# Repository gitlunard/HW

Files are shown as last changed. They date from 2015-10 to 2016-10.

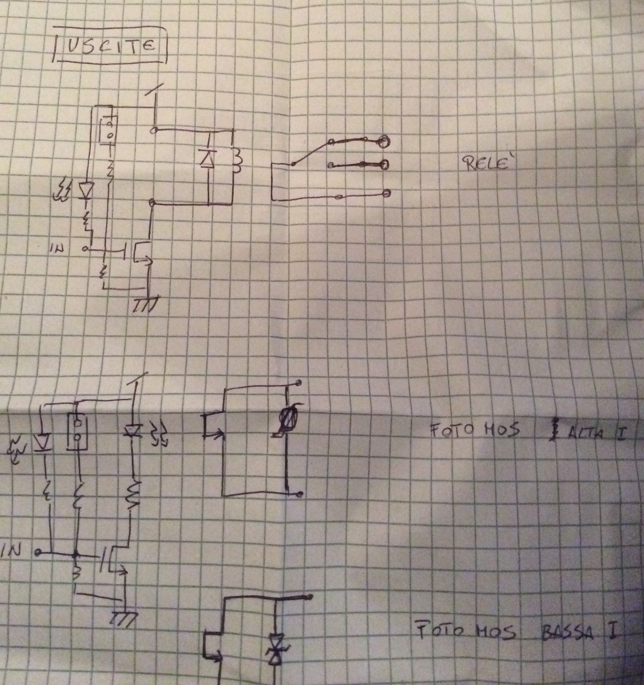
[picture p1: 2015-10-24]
hw-input/00-000-Documenti/Uscite.JPG

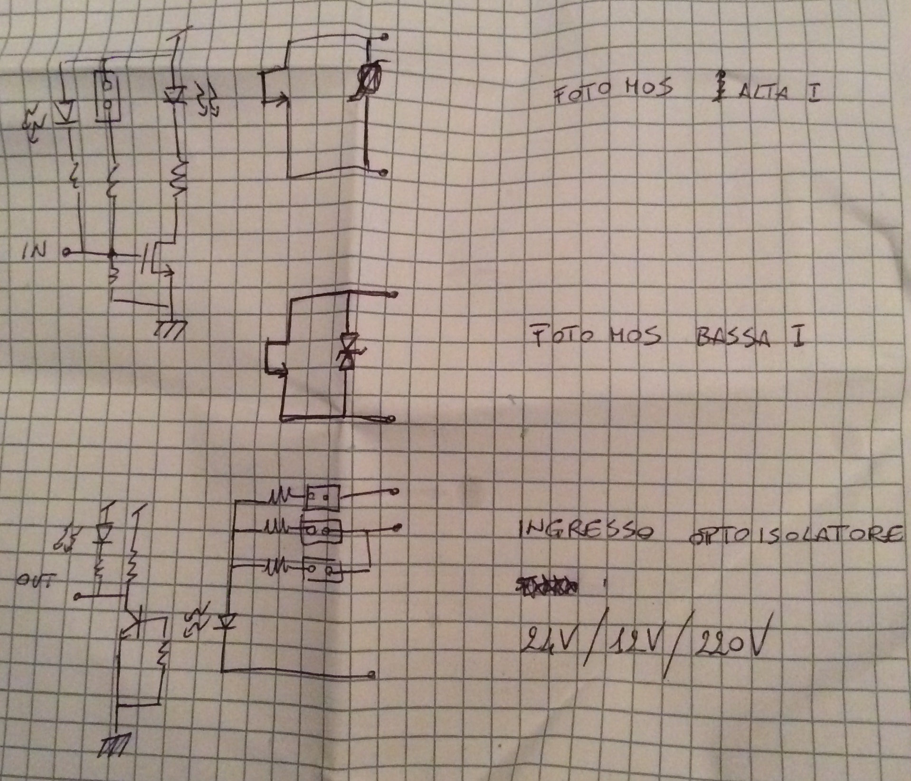
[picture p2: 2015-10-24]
hw-output/00-000-Documenti/ingresso.JPG

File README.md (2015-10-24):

Il progetto è descritto nella cartella hw-doc.
Essendo il progetto giovane, qualcosa potrebbe mancare!!! Aiutaci a completarlo!!!

Per scrivere la documentazione è preferibile utilizzare libreoffice. 
( Lo sappiamo, sull'argomento tool documentazione si apre una discussione infinita...ma abbi pazienza usa libreoffice!)

*********************************************************************************************************************
Se le tue idee, la tua esperienza ed il tuo tempo si comprano con dei soldi allora questo non è il progetto 
che fa per te. Ti consigliamo di lasciar perdere!!!!

Chi ha avviato questo semplice progetto è dell'idea che: 

- Se fai quello che ti piace i soldi non ti servono!!!
- Le idee geniali nascono qunando non ci sono nè pressioni economiche nè pressioni sulle scadenze!!

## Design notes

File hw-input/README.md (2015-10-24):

Progetto HardWare scheda input output

- Input: scheda per due ingressi digitali con optoisolatore. Tensioni di ingresso regolabili.
- Output: circuito stampato unico per diverse tipologie di uscita, photoMOS di potenza, photoMOS di segnale oppure relè. Due uscite per scheda.
- Input/Output: scheda per un ingresso e un'uscita della tipologia definita in Input e Output.

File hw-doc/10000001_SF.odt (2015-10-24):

Specifica fisica unità 10000001

Compilato: L. Colla – L. Balestrieri

Edizione: 1

Revisione: 52

Stato: Bozza

Modifiche: tolti capitoli separati in altri documenti

Data creazione: 13/10/2015

# Indice

# Descrizione generale

Unità di ingressi, uscite digitali isolate.

L'obbietivo è realizzare moduli piccoli e funzionali che realizzano diverse combinazioni di ingressi e uscite, con diverse specifiche di tensione e corrente.

Si vuole modularità di comando, deve essere possibile un comando tramite bus I2C oppure accesso diretto agli input output a 3.3-5Vdc.

## Unità ingressi

PN: 10000001

Unità che prevede due ingressi optoisolati.

La corrente assorbita deve essere al massimo 10 [mA].

La tensione in ingresso deve poter essere programmabile secondo la tabella seguente.

Tensione nominale [V] | Soglia spegnimento [V] | Soglia accensione [V]
5 d.c. | 1,5 | 2,5
12 d.c. | 3 | 8
24 d.c. | 3 | 18
48 d.c. | 5 | 40
220 a.c. | 10 | 160

Le tensioni da tenere in maggior considerazione sono 5, 24 e 220.

## Unità uscite potenza

PN: 10000004

Unità che prevede due uscite a relè o photoMOS.

La corrente in uscita massima deve essere almeno 16A.

La tensione sull'uscita dipenderà dal dispositivo montato indicativamente come la seguente tabella.

Tensione nominale [V] | Corrente [I]
5 d.c. | 5
12 d.c. | 5
24 d.c. | 5
48 d.c. | 10
220 a.c. | 16

Le tensioni da tenere in maggior considerazione sono 5, 24 e 220.

## Unità uscite di segnale

PN: 10000005

Unità che prevede due uscite a relè o photoMOS.

La corrente in uscita massima deve essere almeno 100mA.

La tensione sull'uscita dipenderà dal dispositivo montato indicativamente come la seguente tabella.

Tensione nominale [V] | Corrente [I]
5 d.c. | 500mA
12 d.c. | 250mA
24 d.c. | 250mA
48 d.c. | 250mA
220 a.c. | 100mA

Le tensioni da tenere in maggior considerazione sono 5, 24 e 220.

## Unità mista ingresso e uscita

Unità che prevede un ingresso di quelli già citati ed un'uscita di quelle già citate.

Saranno necessarie due unità distinte per uscita di potenza e uscita di segnale.

# Porte

## Lato logica

Porta a 4 pin per bus I2C e porta a 4 pin per input output diretto.

Il connettore dovrà essere a passo 2.54mm. Con occupazione prevista sia per mezzanina classica che per morsettiera con serraggio a molla.

Si dovrà rispettare il seguente pinout

### Pinout I2C

Pin | Nome | Descrizione
1 | +VDC | Polo positivo alimentazione DC
2 | I2C_SCL | Clock BUS I2C
3 | I2C_SDA | Clock BUS I2C
4 | GND | Massa alimentazione

### Pinout diretto

Pin | Nome | Descrizione
1 | +VDC | Polo positivo alimentazione DC
2 | CMD_IO_0 | Ingresso o uscita 0
3 | CMD_IO_1 | Ingresso o uscita 1
4 | GND | Massa alimentazione

La logica per il collegamento diretto deve essere programmata per funzionare a 3,3V ed essere tollerante fino ai 5,5V.

Nel caso delle uscite non dovranno assorbire dal pin di comando più di 10mA. Per questo motivo le uscite di potenza potrebbero aver bisogno di un transistor di pilotaggio.

### Selezione tipologia di comando

Sulla PCS devono essere possibili entrambi i tipi di comando.

La selezione deve essere fatta mediante variante di montaggio con jumper a saldare o resistenze da 0Ω.

## Lato campo

Porta a 4 pin che fornise due contatti puliti.

Il connettore dovrà essere a passo 5,08mm o 7,62mm. Con occupazione prevsta per morsettiera con serraggio a molla.

Si dovrà rispettare il seguente pinout

### Pinout

Pin | Nome | Descrizione
1 | IO_0_P | Polo positivo uscita numero 0
2 | IO_0_N | Polo negativo uscita numero 0
3 | IO_1_P | Polo positivo uscita numero 1
4 | IO_1_N | Polo negativo uscita numero 1

## Connettori di rimando

Devono essere previsti due connettori di rimando segnali. In questo modo è possibile connettere più moduli che condividono lo stesso BUS I2C ed anche lo stesso integrato I2C expander.

### Porta I2C

Il pinout rimane lo stesso della porta di ingresso, ma deve essere posto lateralmente e realizzato con connettore femmina a passo 2.54.

Il connettore deve prevedere i reofori lato bottom abbastanza lunghi da penetrare nel suo corrispettivo della scheda inferiore.

### Porta ingresso/uscita expander I2C

Il pinout dipende dall'expander utilizzato. Prendendo ad esempio il TCA9554 di TI si hanno 8 ingressi/uscite. Considerando che due porte vengono usate sull'unità base, devono essere rimandate 6 porte.

A fianco di questo connettore deve essere previsto un selettore (microswitch o ponticello a saldare) per determinare quale dei segnali vengono utilizzati dalle schede connesse alla principale.

L'expander I2C di esempio prevede 3 bit di indirizzo programmabile, quindi sullo stesso BUS si riescono ad ottenere 2³·8=64 tra ingressi e uscite.

Pin | Nome | Descrizione
1 | IO_2_CMD | Comando ingresso uscita 2
2 | IO_3_CMD | Comando ingresso uscita 3
3 | IO_4_CMD | Comando ingresso uscita 4
4 | IO_5_CMD | Comando ingresso uscita 5
5 | IO_6_CMD | Comando ingresso uscita 6
6 | IO_7_CMD | Comando ingresso uscita 7

## Indirizzi I2C

Nel caso di pilotaggio I2C va prevista la programmabilità dell'indirizzo attraverso ponticelli a saldare sulla PCS oppure attraverso microswitch.

## Meccanica

La porta lato logica e la porta lato campo dovranno essere su lati opposti della PCS così da facilitare lo sbroglio e ridurre le dimensioni.

Sui lati liberi devono essere piazzate le porte di rimando segnali, in modo che le schede possano essere affiancate o sovrapposte.

Dovranno essere previsti da 2 a 4 fori di fissaggio per viti M3 da decidere in base agli ingombri se metallizzarli o meno.

Se possibile si deve trovare un'involucro plastico idoneo prima dello sbroglio e regolare di conseguenza i fori di fissaggio.

Nello schema a blocchi seguente si descrive a grandi linee anche la disposizione meccanica dei componenti.

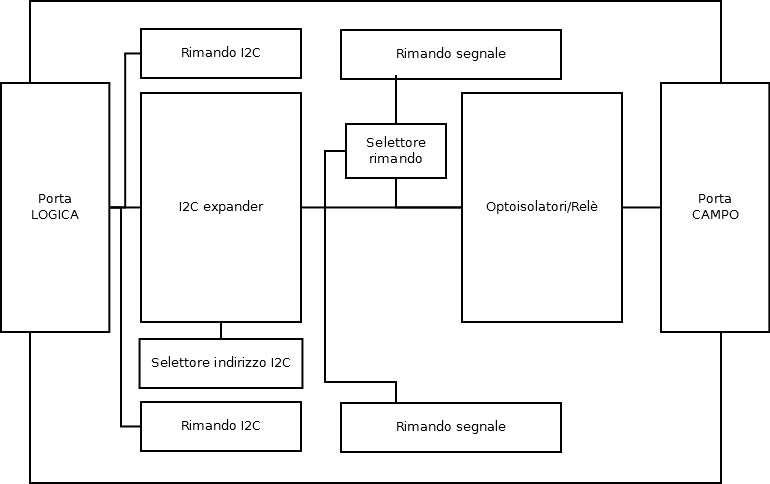
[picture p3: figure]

Illustrazione 1: Schema a blocchi unità IO

OpenS Elettronica condivisa - Specifica fisica unità 10000001

10000001_SF.odt Data: 13/10/2015 Pag. 8 - 8

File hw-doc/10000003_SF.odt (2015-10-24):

Specifica fisica unità 10000003

Compilato: L. Colla – L. Balestrieri

Edizione: 0

Revisione: 54

Stato: Bozza

Modifiche: nessuna

Data creazione: 22/11/2014

# Indice

# Descrizione generale

Unità di distribuzione alimentazione.

L'obbiettivo è di realizzare una scheda semplice di distribuzione alimentazione.

Data una alimentazione principale in ingresso, possibile anche 220Vac, deve essere distribuita a porte secondarie. Questo viene utilizzato per semplificare il cablaggio di diversi moduli di una unità principale.

In questa unità devono essere previsti gli alloggiamenti per eventuali dispositivi di protezione, come soppressori bidirezionali, induttori, filtri di modo comune, e varistori.

Va previsto un'assorbimento pari a 10A come carico delle piste.

# Porte

## Ingresso

Porta 3 pin.

Il connettore dovrà essere a passo 5,08mm o 7,62mm. Con occupazione prevsta per morsettiera con serraggio a molla.

Si dovrà rispettare il seguente pinout

### Pinout

Pin | Nome | Descrizione
1 | +V | Polo positivo rete di alimentazione
2 | -V | Polo negativo rete di alimentazione
3 | PGND | Terra di protezione

## Uscita

Porta 3 pin ripetuta due volte.

Il connettore dovrà essere a passo 5,08mm o 7,62mm. Con occupazione prevsta per morsettiera con serraggio a molla.

Si dovrà rispettare il seguente pinout per ogni porta

### Pinout

Pin | Nome | Descrizione
1 | +V | Polo positivo rete di alimentazione
2 | -V | Polo negativo rete di alimentazione
3 | PGND | Terra di protezione

## Connettori di rimando

Devono essere previsti due connettori di rimando segnali. In questo modo è possibile connettere più moduli che distribuiscono la stessa rete di alimentazione

Il pinout è il seguente

### Pinout

Pin | Nome | Descrizione
1 | +V | Polo positivo rete di alimentazione
2 | -V | Polo negativo rete di alimentazione
3 | PGND | Terra di protezione

## Meccanica

La porta ingresso e la porta uscita dovranno essere su lati opposti della PCS così da facilitare lo sbroglio e ridurre le dimensioni.

Sui lati liberi devono essere piazzate le porte di rimando segnali, in modo che le schede possano essere affiancate o sovrapposte.

Dovranno essere previsti da 2 a 4 fori di fissaggio per viti M3 da decidere in base agli ingombri se metallizzarli o meno.

Se possibile si deve trovare un'involucro plastico idoneo prima dello sbroglio e regolare di conseguenza i fori di fissaggio.

Nello schema a blocchi seguente si descrive a grandi linee anche la disposizione meccanica dei componenti.

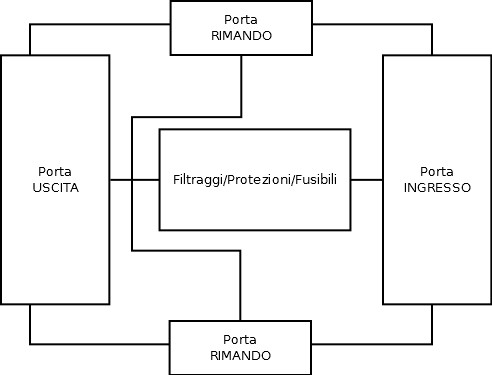
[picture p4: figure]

Illustrazione 1: Schema a blocchi distribuzione

OpenS Elettronica condivisa - Specifica fisica unità 10000003

10000003_SF.odt Data: 22/11/2014 Pag. 3 - 5

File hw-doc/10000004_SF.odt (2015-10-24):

Specifica fisica unità 10000004

Compilato: L. Colla – L. Balestrieri

Edizione: 0

Revisione: 62

Stato: Bozza

Modifiche: -

Data creazione: 09/03/2015

# Indice

# Descrizione generale

Unità di interfaccia seriale, deve realizzare la conversione dell'uscita seriale del microcontrollore a standard RS232 o USB 2.0.

Non vengono usati i pin relativi ai controlli di flusso, si portano solo i fili TX e RX.

## Standard RS232 su RJ45

Per la conversione a standard RS232 si usa il dispositivo RS3232 alimentabile tra 3V e 5V. Il connettore deve essere RJ45 senza led in pacchetto metallico.

## Standard USB su micro-B-USB

Usare il dispositivo FT232R per il passaggio diretto a USB 2.0. In sviluppi futuri è possibile usare anche l'alimentazione da USB per alimentare il convertitore e altre logiche esterne. Il connettore deve essere micro-B-USB standard per dispositivi portatili.

# Porte

## Lato microcontrollore

Porta a 4 pin per connesione bus seriale e alimentazione.

Il connettore dovrà essere a passo 2.54mm. Con occupazione prevista sia per mezzanina classica che per morsettiera con serraggio a molla.

Si dovrà rispettare il seguente pinout

### Pinout I2C

Pin | Nome | Descrizione
1 | +VDC | Polo positivo alimentazione DC
2 | SER_TX | Dato TX (uscita)
3 | SER_RX | Dato RX (ingresso)
4 | GND | Massa alimentazione

## Lato campo

### Pinout RJ45

Porta RJ45 con calotta metallica in standard console Cisco.

Si dovrà rispettare il seguente pinout

Riferimento: http://www.cisco.com/en/US/docs/security/pix/pix70/hw/installation/guide/append.html#wp1011710

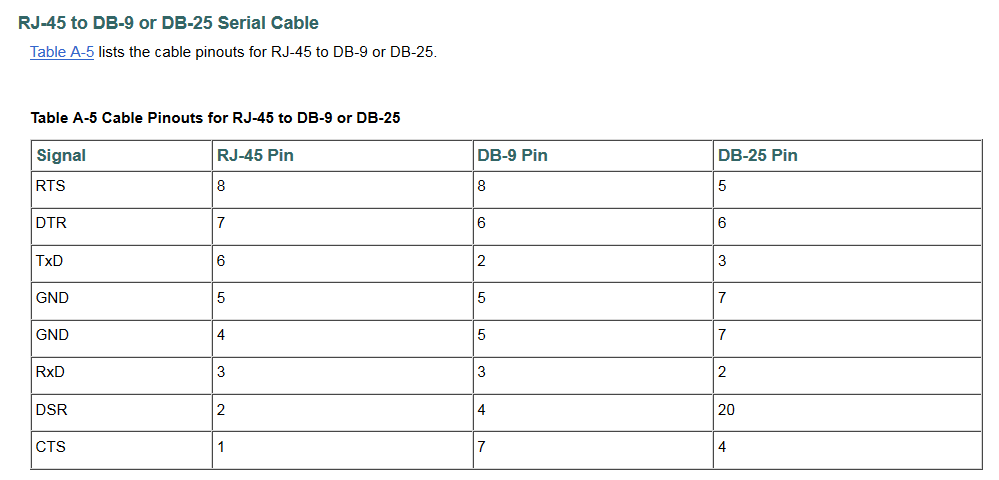
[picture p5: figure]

### Pinout USB

Porta micro-B con calotta metallica standard.

Pinout da verificare.

## Meccanica

La porta lato microcontrollore e la porta lato campo dovranno essere su lati opposti della PCS così da facilitare lo sbroglio e ridurre le dimensioni.

Dovranno essere previsti da 2 a 4 fori di fissaggio per viti M3 da decidere in base agli ingombri se metallizzarli o meno.

Se possibile si deve trovare un'involucro plastico idoneo prima dello sbroglio e regolare di conseguenza i fori di fissaggio.

Nello schema a blocchi seguente si descrive a grandi linee anche la disposizione meccanica dei componenti.

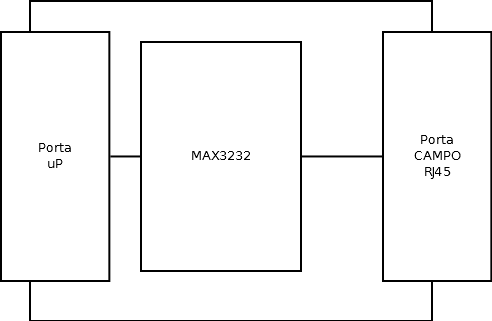
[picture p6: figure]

Illustrazione 1: Schema a blocchi seriale RJ45

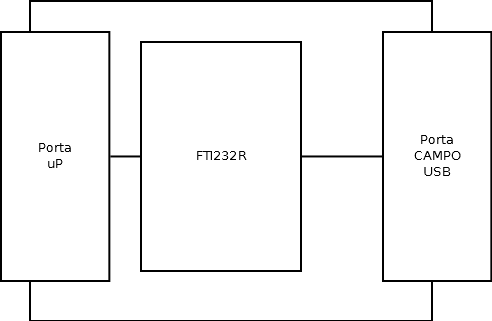
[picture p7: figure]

Illustrazione 2: Schema a blocchi seriale USB

OpenS Elettronica condivisa - Specifica fisica unità 1000000

10000004_SF.odt Data: 09/03/2015 Pag. 5 - 5

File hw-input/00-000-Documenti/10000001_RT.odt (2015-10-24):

Rapporto di test unità 10000001

Compilato: L. Colla – L. Balestrieri

Edizione: 0

Revisione: 58

Stato: Bozza

Modifiche:

Data creazione: 07/09/2015

# Indice

# Descrizione generale

Rapporto prove su prototipi scheda ingressi.

## PCB errato

I piani dei layer interni non sono stati aggiornati prima della produzione.

Il risultato sono il layer VCC e GND in corto, inoltre altre piste risultano annegate nei layer.

La scheda così come è risulta compromessa.

E' possibile utilizzare la scheda come sottomodulo, senza montare l'expander I2C.

Operazioni da eseguire.

- Eliminare tutti i componenti comrpesere tutte le resistenze 0Ω. Lasciare solamente la parte relativa all'optoisolatore e le sue resistenze di polarizzazione.
- Forare le vias di VDD e GND connesse a R10 e R11. E ricreare le connessioni filate verso il primo connettore libero.
- Collegare R1 per connettere IO_0_CMD a IO_2_CMD.
- Il comando IO_0_CMD è recuperato.
- Eliminare la vias a fianco del pin 4 di IC2 e ricreare la connessione andando al primo pin connesso a IO_3_CMD.
- Eliminare le vias di VDD e GND a fianco di R12 ed R13 e ricreare le connessioni filate verso il primo connettore libero.
- Il comando IO_1_CMD è recuperato.

OpenS Elettronica condivisa - Rapporto di test unità 10000001

10000001_RT.odt Data: 07/09/2015 Pag. 2 - 3

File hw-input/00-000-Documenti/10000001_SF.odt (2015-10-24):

Specifica fisica unità 10000001

Compilato: L. Colla – L. Balestrieri

Edizione: 1

Revisione: 6

Stato: Prima emissione

Modifiche: Pulizia documento con sole specifiche unità ingressi.

Aggiornamento documento per nuova versione HW

Data creazione: 17/10/2015

# Indice

# Descrizione generale

Unità di ingressi isolati.

L'obbietivo è realizzare moduli piccoli e funzionali che realizzano diverse funzioni di interfaccia verso il campo, tutti compatibili meccanicamente tra loro.

Si vuole modularità di comando, deve essere possibile un comando tramite bus I2C oppure accesso diretto agli input output a 3.3-5Vdc.

## Unità ingressi

Unità che prevede due ingressi optoisolati.

La corrente assorbita deve essere al massimo 10 [mA].

La tensione in ingresso deve poter essere programmabile secondo la tabella seguente.

Tensione nominale [V] | Soglia spegnimento [V] | Soglia accensione [V]
5 d.c. | 1,5 | 2,5
12 d.c. | 3 | 8
24 d.c. | 3 | 18
48 d.c. | 5 | 40
220 a.c. | 10 | 160

Le tensioni da tenere in maggior considerazione sono 5, 24 e 220.

# Porte

## Lato logica

Porta a 4 pin per bus I2C e porta a 4 pin per input output diretto.

Il connettore dovrà essere a passo 2.54mm. Con occupazione prevista sia per mezzanina classica che per morsettiera con serraggio a molla.

Si dovrà rispettare il seguente pinout

### Pinout I2C

Pin | Nome | Descrizione
1 | +VDC | Polo positivo alimentazione DC
2 | I2C_SCL | Clock BUS I2C
3 | I2C_SDA | Clock BUS I2C
4 | GND | Massa alimentazione

### Pinout diretto

Pin | Nome | Descrizione
1 | +VDC | Polo positivo alimentazione DC
2 | CMD_IO_0 | Ingresso o uscita 0
3 | CMD_IO_1 | Ingresso o uscita 1
4 | GND | Massa alimentazione

La logica per il collegamento diretto deve essere programmata per funzionare a 3,3V ed essere tollerante fino ai 5,5V.

### Selezione tipologia di comando

Sulla PCS devono essere possibili entrambi i tipi di comando.

La selezione deve essere fatta mediante variante di montaggio con jumper a saldare o resistenze da 0Ω.

## Lato campo

Porta a 4 pin che fornise due contatti puliti.

Il connettore dovrà essere a passo 5,08mm o 7,62mm. Con occupazione prevsta per morsettiera con serraggio a molla.

Si dovrà rispettare il seguente pinout

### Pinout

Pin | Nome | Descrizione
1 | IO_0_P | Polo positivo uscita numero 0
2 | IO_0_N | Polo negativo uscita numero 0
3 | IO_1_P | Polo positivo uscita numero 1
4 | IO_1_N | Polo negativo uscita numero 1

## Connettori di rimando

Devono essere previsti due connettori di rimando segnali. In questo modo è possibile connettere più moduli che condividono lo stesso BUS I2C ed anche lo stesso integrato I2C expander.

### Porta I2C

Il pinout rimane lo stesso della porta di ingresso, ma deve essere posto lateralmente e realizzato con connettore femmina a passo 2.54.

Il connettore deve prevedere i reofori lato bottom abbastanza lunghi da penetrare nel suo corrispettivo della scheda inferiore.

### Porta ingresso/uscita expander I2C

Il pinout dipende dall'expander utilizzato. Prendendo ad esempio il TCA9554 di TI si hanno 8 ingressi/uscite. Considerando che due porte vengono usate sull'unità base, devono essere rimandate 6 porte.

A fianco di questo connettore deve essere previsto un selettore (microswitch o ponticello a saldare) per determinare quale dei segnali vengono utilizzati dalle schede connesse alla principale.

L'expander I2C di esempio prevede 3 bit di indirizzo programmabile, quindi sullo stesso BUS si riescono ad ottenere 2³·8=64 tra ingressi e uscite.

Pin | Nome | Descrizione
1 | IO_2_CMD | Comando ingresso uscita 2
2 | IO_3_CMD | Comando ingresso uscita 3
3 | IO_4_CMD | Comando ingresso uscita 4
4 | IO_5_CMD | Comando ingresso uscita 5
5 | IO_6_CMD | Comando ingresso uscita 6
6 | IO_7_CMD | Comando ingresso uscita 7

## Indirizzi I2C

Nel caso di pilotaggio I2C va prevista la programmabilità dell'indirizzo attraverso ponticelli a saldare sulla PCS oppure attraverso microswitch.

## Meccanica

La porta lato logica e la porta lato campo dovranno essere su lati opposti della PCS così da facilitare lo sbroglio e ridurre le dimensioni.

Sui lati liberi devono essere piazzate le porte di rimando segnali, in modo che le schede possano essere affiancate o sovrapposte.

Dovranno essere previsti da 2 a 4 fori di fissaggio per viti M3 da decidere in base agli ingombri se metallizzarli o meno.

Se possibile si deve trovare un'involucro plastico idoneo prima dello sbroglio e regolare di conseguenza i fori di fissaggio.

Nello schema a blocchi seguente si descrive a grandi linee anche la disposizione meccanica dei componenti.


Illustrazione 1: Schema a blocchi unità IO

## Possibili tipologie di comando

### Schmitt trigger

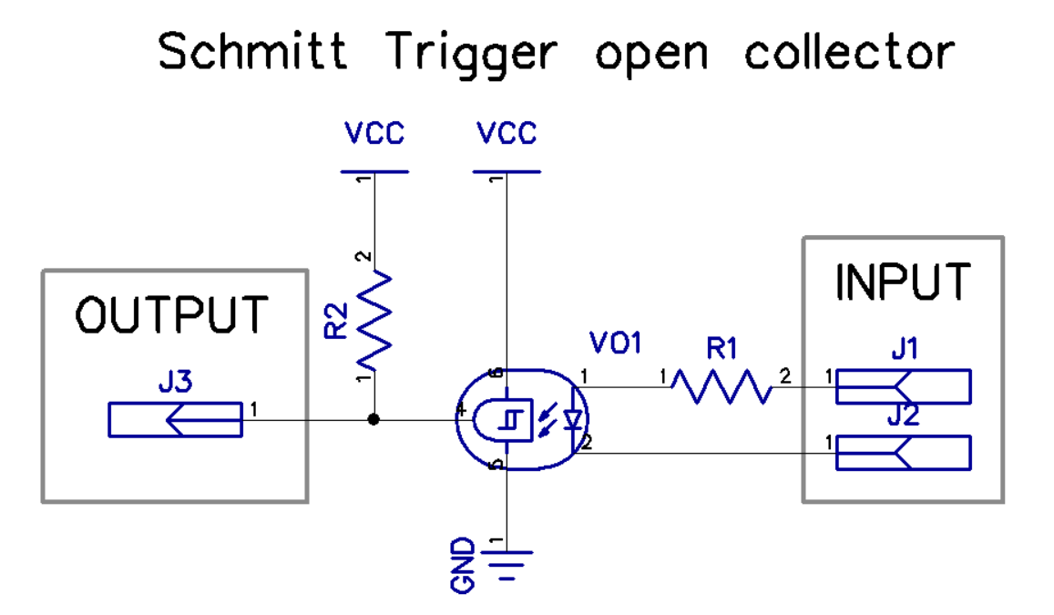
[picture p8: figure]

Tipologia optoisolatore Fairchild H11L1M 0,88€

Si può fare solo la configurazione pull-down perchè l'optoisolatore esce come un open-collector. Integra già il trigger di Schmitt riducendo notevolmente i disturbi.

### General-purpose pull-down

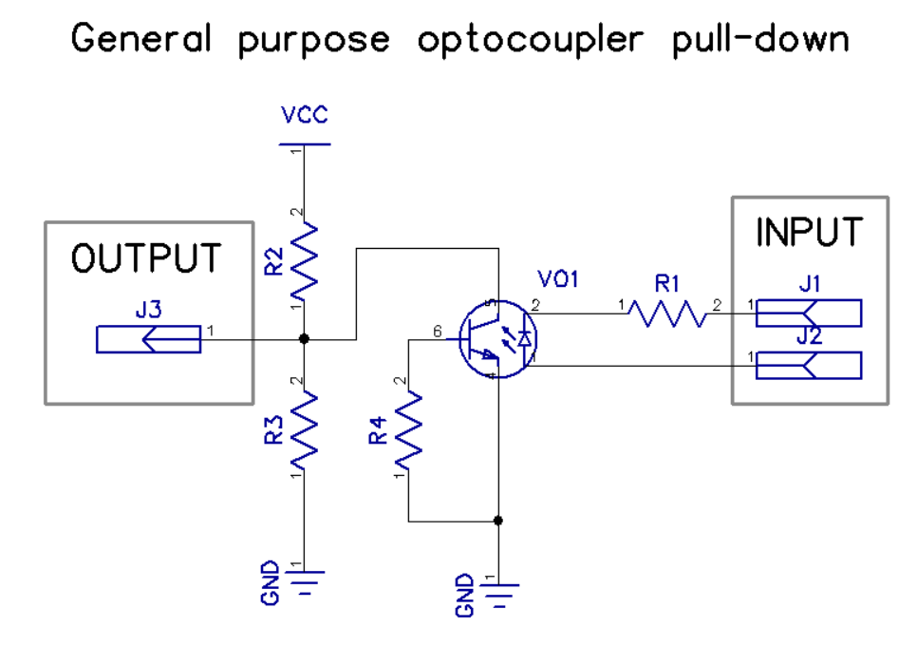
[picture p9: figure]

Tipologia optoisolatore 4N35M, H11A1, TLP291 0,5€

Si può decidere di spostare a pull-up l'optoaccoppiatore. Si può optare per optoisolatori semplici e piccoli come TLP291 senza la connessione di base. Per quanto riguarda il 4N35 è un package standard, quindi con molte alternative.

### Versione mista

Si può realizzare la seconda versione ed in uscita inserire uno Schmitt trigger a componenti discreti o integrato, ma considerando il costo della prima soluzione risulta sicuramente più vantaggiosa.

### Considerazioni tensione in ingresso e resistenza di polarizzazione opto

Nella versione più semplice è costretti ad usare una resistenza per polarizzare il diodo dell'optoaccoppiatore. Questo definisce direttamente la tensione di ingresso e la soglia di attivazione. E' possibile sostituire la resistenza con il circuito seguente, questo permette di adattarsi alla tensione di ingresso, rimane problematica la definizione della soglia di attivazione, in questo caso sarebbe sempre fissa allo stesso valore.

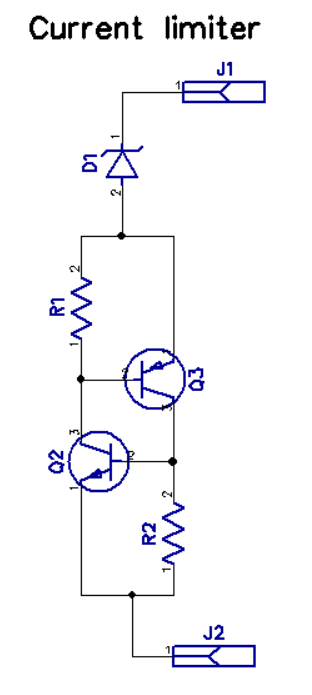
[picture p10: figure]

OpenS Elettronica condivisa - Specifica fisica unità 10000001

10000001_SF.odt Data: 17/10/2015 Pag. 8 - 8

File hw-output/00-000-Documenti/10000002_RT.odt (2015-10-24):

Rapporto di test unità 10000002

Compilato: L. Colla – L. Balestrieri

Edizione: 0

Revisione: 54

Stato: Bozza

Modifiche:

Data creazione: 07/09/2015

# Indice

# Descrizione generale

Rapporto prove su prototipi scheda uscite.

## PCB errato

I piani dei layer interni non sono stati aggiornati prima della produzione.

Il risultato sono il layer VCC e GND in corto.

Sono stati forati 3 vias attorno a C1 e C2 per eliminare il corto e riportate le connessioni sui pin 1 e 4 del primo connettore libero.

OpenS Elettronica condivisa - Rapporto di test unità 10000002

10000002_RT.odt Data: 07/09/2015 Pag. 1 - 3

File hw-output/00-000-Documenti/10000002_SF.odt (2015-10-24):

Specifica fisica unità 10000002

Compilato: L. Colla – L. Balestrieri

Edizione: 0

Revisione: 20

Stato: Prima emissione

Modifiche: Pulizia documento con sole specifiche unità uscite.

Aggiornamento documento per nuova versione HW

Data creazione: 17/10/2015

# Indice

# Descrizione generale

Unità uscite digitali isolate.

L'obbietivo è realizzare moduli piccoli e funzionali che realizzano diverse funzioni di interfaccia verso il campo, tutti compatibili meccanicamente tra loro.

Si vuole modularità di comando, deve essere possibile un comando tramite bus I2C oppure accesso diretto agli input output a 3.3-5Vdc.

## Unità uscite potenza

Unità che prevede due uscite a relè o photoMOS.

La tensione sull'uscita e la relativa corrente massima dipenderà dal dispositivo montato indicativamente come la seguente tabella.

Tensione nominale [V] | Corrente [I]
5 d.c. | 5
12 d.c. | 5
24 d.c. | 5
48 d.c. | 10
220 a.c. | 16

Le tensioni da tenere in maggior considerazione sono 5, 24 e 220.

# Porte

## Lato logica

Porta a 4 pin per bus I2C e porta a 4 pin per input output diretto.

Il connettore dovrà essere a passo 2.54mm. Con occupazione prevista sia per mezzanina classica che per morsettiera con serraggio a molla.

Si dovrà rispettare il seguente pinout

### Pinout I2C

Pin | Nome | Descrizione
1 | +VDC | Polo positivo alimentazione DC
2 | I2C_SCL | Clock BUS I2C
3 | I2C_SDA | Clock BUS I2C
4 | GND | Massa alimentazione

### Pinout diretto

Pin | Nome | Descrizione
1 | +VDC | Polo positivo alimentazione DC
2 | CMD_IO_0 | Ingresso o uscita 0
3 | CMD_IO_1 | Ingresso o uscita 1
4 | GND | Massa alimentazione

La logica per il collegamento diretto deve essere programmata per funzionare a 3,3V ed essere tollerante fino ai 5,5V.

Ogni uscita non dovrà assorbire dal pin di comando più di 10mA. Per questo motivo le uscite di potenza potrebbero aver bisogno di un transistor di pilotaggio.

### Selezione tipologia di comando

Sulla PCS devono essere possibili entrambi i tipi di comando.

La selezione deve essere fatta mediante variante di montaggio con jumper a saldare o resistenze da 0Ω.

## Lato campo

Porta a 4 pin che fornise due contatti puliti.

Il connettore dovrà essere a passo 5,08mm o 7,62mm. Con occupazione prevsta per morsettiera con serraggio a molla.

Si dovrà rispettare il seguente pinout

### Pinout

Pin | Nome | Descrizione
1 | IO_0_P | Polo positivo uscita numero 0
2 | IO_0_N | Polo negativo uscita numero 0
3 | IO_1_P | Polo positivo uscita numero 1
4 | IO_1_N | Polo negativo uscita numero 1

## Connettori di rimando

Devono essere previsti due connettori di rimando segnali. In questo modo è possibile connettere più moduli che condividono lo stesso BUS I2C ed anche lo stesso integrato I2C expander.

### Porta I2C

Il pinout rimane lo stesso della porta di ingresso, ma deve essere posto lateralmente e realizzato con connettore femmina a passo 2.54.

Il connettore deve prevedere i reofori lato bottom abbastanza lunghi da penetrare nel suo corrispettivo della scheda inferiore.

### Porta ingresso/uscita expander I2C

Il pinout dipende dall'expander utilizzato. Prendendo ad esempio il TCA9554 di TI si hanno 8 ingressi/uscite. Considerando che due porte vengono usate sull'unità base, devono essere rimandate 6 porte.

A fianco di questo connettore deve essere previsto un selettore (microswitch o ponticello a saldare) per determinare quale dei segnali vengono utilizzati dalle schede connesse alla principale.

L'expander I2C di esempio prevede 3 bit di indirizzo programmabile, quindi sullo stesso BUS si riescono ad ottenere 2³·8=64 tra ingressi e uscite.

Pin | Nome | Descrizione
1 | IO_2_CMD | Comando ingresso uscita 2
2 | IO_3_CMD | Comando ingresso uscita 3
3 | IO_4_CMD | Comando ingresso uscita 4
4 | IO_5_CMD | Comando ingresso uscita 5
5 | IO_6_CMD | Comando ingresso uscita 6
6 | IO_7_CMD | Comando ingresso uscita 7

## Indirizzi I2C

Nel caso di pilotaggio I2C va prevista la programmabilità dell'indirizzo attraverso ponticelli a saldare sulla PCS oppure attraverso microswitch.

## Meccanica

La porta lato logica e la porta lato campo dovranno essere su lati opposti della PCS così da facilitare lo sbroglio e ridurre le dimensioni.

Sui lati liberi devono essere piazzate le porte di rimando segnali, in modo che le schede possano essere affiancate o sovrapposte.

Dovranno essere previsti da 2 a 4 fori di fissaggio per viti M3 da decidere in base agli ingombri se metallizzarli o meno.

Se possibile si deve trovare un'involucro plastico idoneo prima dello sbroglio e regolare di conseguenza i fori di fissaggio.

Nello schema a blocchi seguente si descrive a grandi linee anche la disposizione meccanica dei componenti.


Illustrazione 1: Schema a blocchi unità IO

## Possibili tipologie di comando

A seconda del tipo di integrato I2C utilizzato possono presentarsi diverse tipologie di driver in uscita, push-pull o open-drain, a bassa o ad alta corrente.

### Driver push-pull

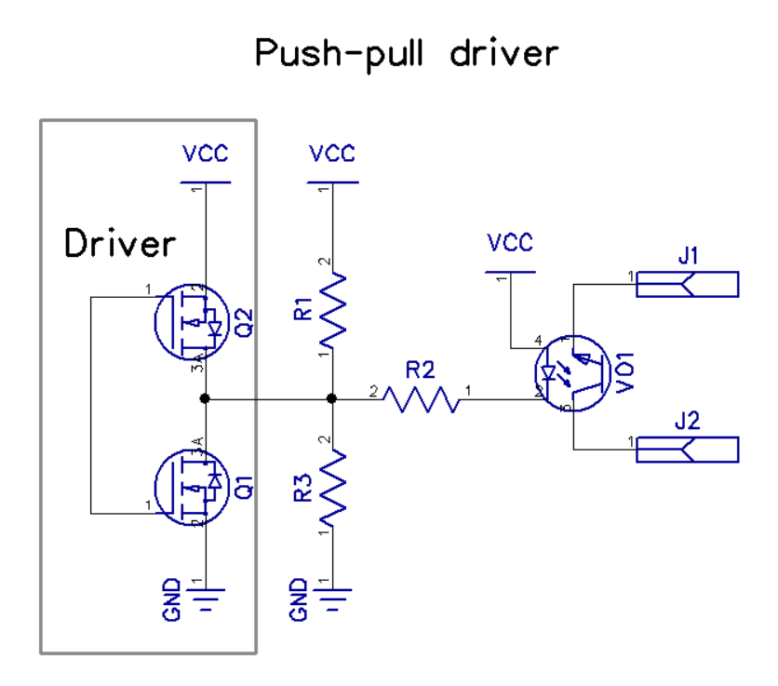
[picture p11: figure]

Se il driver ha la possibilità di pilotare direttamente il diodo del photoMOS, si può usare questo schema, con R2 si definisce la corrente di pilotaggio del diodo. R1 ed R3 definiscono la situazione di partenza del comando.

### Driver push-pull con transistor driver

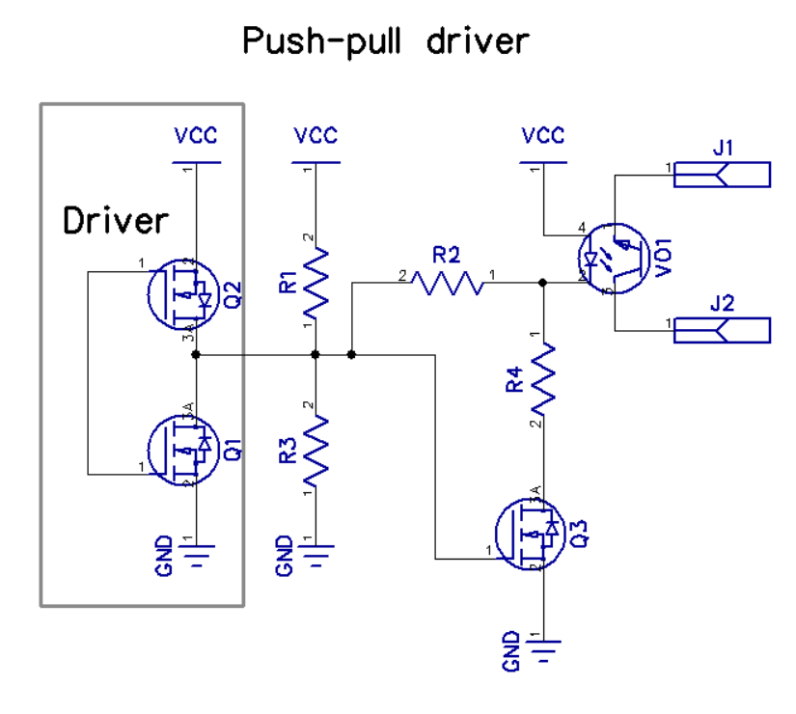
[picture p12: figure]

Il driver push-pull può essere a bassa corrente e pilotare il transistor che pilota il diodo. In questo caso montando R2 e smontando Q3 e R4 si torna al caso di pilotaggio diretto. R4 definisce la corrente di pilotaggio del diodo. R1 ed R3 definiscono la situazione di partenza del comando. In questo caso il driver può essere anche open-drain ma in questo caso si può ottenere solamente un normalmente eccitato.

### Driver open-drain

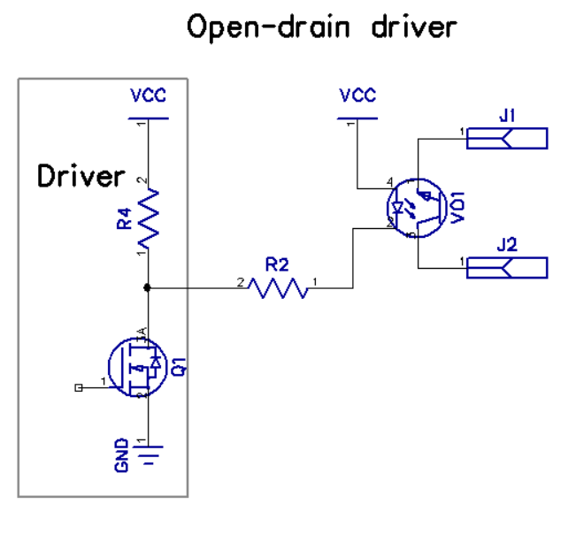
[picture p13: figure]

Nel caso di driver open-drain con possibilità di pilotaggio diretto del diodo, si può ridurre al minimo il numero di componenti. R2 imposta la corrente di pilotaggio del diodo. Si può solo realizzare una tipologia di normalmente diseccitato.

### Driver open-drain o push-pull

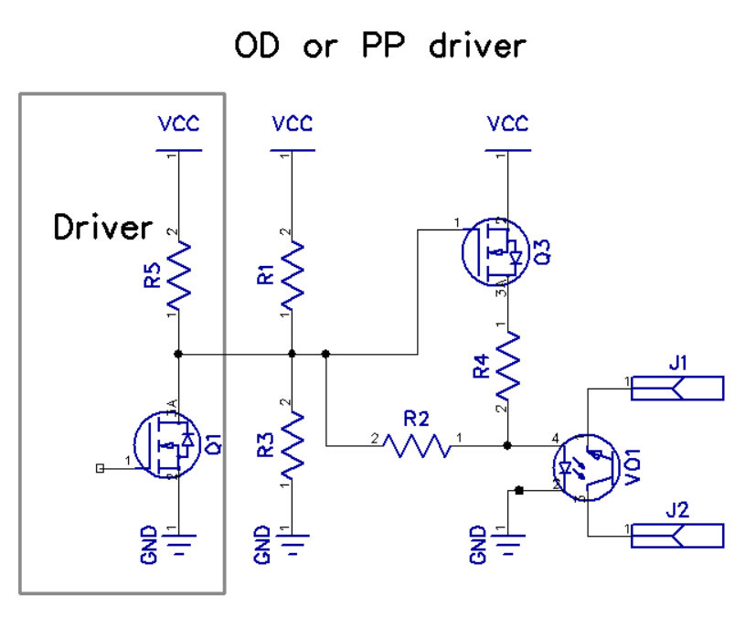
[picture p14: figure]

Nel caso di driver open-drain a bassa corrente il pilotaggio deve essere effettuato in questo modo per avere un'uscita normalmente diseccitata. La stessa logica può essere usata per driver di tipo push-pull, in questo caso risulta analoga al caso già considerato. Sia con driver push-pull che con driver open-drain si può tornare al pilotaggio diretto senza transistor. Nel caso di pilotaggio diretto open-drain si deve montare R1 per permettere l'accensione del diodo ed in ogni caso si ottiene solo un'uscita normalmente eccitata.

### Preferenza

L'ultima soluzione risulta la meglio spendibile in tutti i casi di pilotaggio. Se si vuole risparmiare il numero di componenti ed evitare il transistor di pilotaggio, risulta più sicuro usare un driver di uscita di tipo push-pull.

Come I2C expander adatto si può iniziare TCA9554 che integra uscite push-pull.

OpenS Elettronica condivisa - Specifica fisica unità 10000002

10000002_SF.odt Data: 17/10/2015 Pag. 8 - 10

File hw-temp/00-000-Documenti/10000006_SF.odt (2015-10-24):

Specifica fisica unità 10000006

Compilato: L. Colla – L. Balestrieri

Edizione: 1

Revisione: 12

Stato: Prima emissione

Modifiche:

Data creazione: 20/10/2015

# Indice

# Descrizione generale

Unità di misurazione temperatura.

L'obbietivo è realizzare moduli piccoli e funzionali che realizzano diverse funzioni di interfaccia verso il campo, tutti compatibili meccanicamente tra loro.

Si vuole modularità di comando, deve essere possibile un comando tramite bus I2C oppure accesso diretto agli input output a 3.3-5Vdc.

## Unità misurazione temperatura

Unità che prevede due ingressi per sonde PT100 o termocoppie. La temperatura da misurare è quella ambiente, quindi si ipotizza -40/+85 °C.

Deve essere possibile connettere sonde di una decina di metri di lunghezza, quindi si deve valutare la massima portata di sonde con misurazione a 4 fili.

# Porte

## Lato logica

Porta a 4 pin per bus I2C.

Il connettore dovrà essere a passo 2.54mm. Con occupazione prevista sia per mezzanina classica che per morsettiera con serraggio a molla.

Si dovrà rispettare il seguente pinout

### Pinout I2C

Pin | Nome | Descrizione
1 | +VDC | Polo positivo alimentazione DC
2 | I2C_SCL | Clock BUS I2C
3 | I2C_SDA | Clock BUS I2C
4 | GND | Massa alimentazione

## Lato campo

Porta a 4 pin che permette la connessione di una sonda a 4 fili.

Il connettore dovrà essere a passo 5,08mm o 7,62mm. Con occupazione prevsta per morsettiera con serraggio a molla.

Si dovrà rispettare il seguente pinout

### Pinout

Pin | Nome | Descrizione
1 | SEN_0_AP | Polo positivo alimentazione sonda
2 | SEN_0_SP | Polo positivo misurazione sonda
3 | SEN_0_SN | Polo negativo misurazione sonda
4 | SEN_0_AN | Polo negativo alimentazione sonda

## Connettori di rimando

Devono essere previsti due connettori di rimando segnali. In questo modo è possibile connettere più moduli che condividono lo stesso BUS I2C ed anche lo stesso integrato I2C expander.

### Porta I2C

Il pinout rimane lo stesso della porta di ingresso, ma deve essere posto lateralmente e realizzato con connettore femmina a passo 2.54.

Il connettore deve prevedere i reofori lato bottom abbastanza lunghi da penetrare nel suo corrispettivo della scheda inferiore.

## Indirizzi I2C

Nel caso di pilotaggio I2C va prevista la programmabilità dell'indirizzo attraverso ponticelli a saldare sulla PCS oppure attraverso microswitch.

## Meccanica

La porta lato logica e la porta lato campo dovranno essere su lati opposti della PCS così da facilitare lo sbroglio e ridurre le dimensioni.

Sui lati liberi devono essere piazzate le porte di rimando segnali, in modo che le schede possano essere affiancate o sovrapposte.

Dovranno essere previsti da 2 a 4 fori di fissaggio per viti M3 da decidere in base agli ingombri se metallizzarli o meno.

Se possibile si deve trovare un'involucro plastico idoneo prima dello sbroglio e regolare di conseguenza i fori di fissaggio.

Nello schema a blocchi seguente si descrive a grandi linee anche la disposizione meccanica dei componenti.

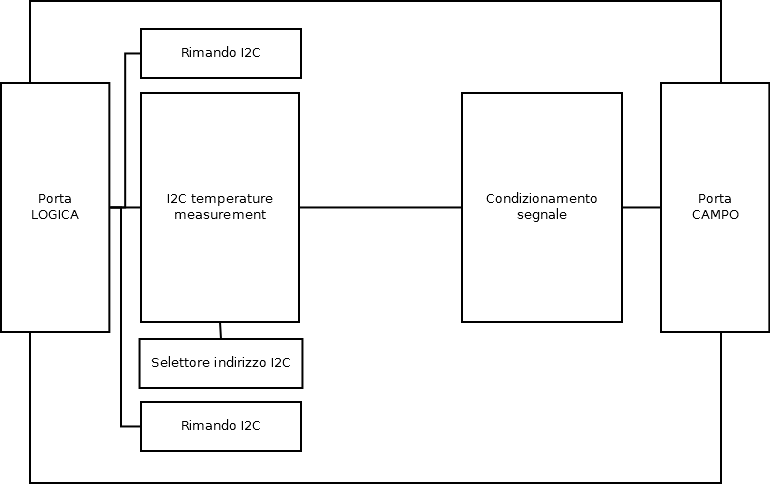
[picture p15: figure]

Illustrazione 1: Schema a blocchi unità temperatura

## Componenti

### Misura di temperatura

MAX31865 3.5€ disponibile su mouser. Permette la lettura di RTD a 4 fili e fornisce un'interfaccia SPI

### Conversione I2C to SPI

SC18IS602B 2.4€ disponibile su digikey. Permette la conversione di un BUS I2C in BUS SPI. Va gestito con librerie ad hoc e programmato.

OpenS Elettronica condivisa - Specifica fisica unità 10000006

10000006_SF.odt Data: 20/10/2015 Pag. 4 - 5

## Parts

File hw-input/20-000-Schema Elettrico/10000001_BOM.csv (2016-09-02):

Source: | C:/progetti_20/OpenS/HW/hw-input/20-000-Schema Elettrico/10000001.sch
Date: | 02/09/2016 09:24:14
Tool: | Eeschema 4.0.3-stable
Generator: | C:/programmi_20/KiCad/bin/scripting/plugins/bom_csv_grouped_by_value.py
Component Count: | 34
Individual Components:
Item | Qty | Reference(s) | Value | LibPart | Footprint | Datasheet | CERAMIC | MF | MF_PN | NOPOP | VAL | VALUE | VOLTAGE | Value
 |  | C1 | C_100n_0603_10_X7R_25V | os_capacitor_SMD:C_100n_0603_10_X7R_25V | Capacitors_SMD:C_0603 |  | X7R | Murata | GRM188R71E104KA01D | 0 |  | 100n | 25V | C_100n_0603_10_X7R_25V
 |  | C2 | C_1u_0603_10_X7R_25V | os_capacitor_SMD:C_1u_0603_10_X7R_25V | Capacitors_SMD:C_0603 |  | X7R | Murata | GRJ188R71E105KE11D | 0 |  | 1u | 25V | C_1u_0603_10_X7R_25V
 |  | D1 | TVS_SMC_49.1V | tvs:TVS_SMC_49.1V | Diodes_SMD:SMC_Standard |  |  | BOURNS | SMLJ40CA | 0 |  |  |  | 49.1V
 |  | D2 | TVS_SMC_49.1V | tvs:TVS_SMC_49.1V | Diodes_SMD:SMC_Standard |  |  | BOURNS | SMLJ40CA | 0 |  |  |  | 49.1V
 |  | P1 | PLUG_01X04_254 | os_conn_strip:PLUG_01X04_254 | Socket_Strips:Socket_Strip_Straight_1x04 |  |  | Harwin | M20-7820446 | 0 | M20-7820446 |  |  | PLUG_01X04_254
 |  | P2 | PLUG_01X04_254 | os_conn_strip:PLUG_01X04_254 | Socket_Strips:Socket_Strip_Straight_1x04 |  |  | Harwin | M20-7820446 | 0 | M20-7820446 |  |  | PLUG_01X04_254
 |  | P3 | PLUG_01X04_254 | os_conn_strip:PLUG_01X04_254 | Socket_Strips:Socket_Strip_Straight_1x04 |  |  | Harwin | M20-7820446 | 0 | M20-7820446 |  |  | PLUG_01X04_254
 |  | P4 | PLUG_01X04_254 | os_conn_strip:PLUG_01X04_254 | Socket_Strips:Socket_Strip_Straight_1x04 |  |  | Harwin | M20-7820446 | 0 | M20-7820446 |  |  | PLUG_01X04_254
 |  | P5 | PLUG_01X04_254 | os_conn_strip:PLUG_01X04_254 | Socket_Strips:Socket_Strip_Straight_1x04 |  |  | Harwin | M20-7820446 | 0 | M20-7820446 |  |  | PLUG_01X04_254
 |  | P6 | PLUG_01X04_254 | os_conn_strip:PLUG_01X04_254 | Socket_Strips:Socket_Strip_Straight_1x04 |  |  | Harwin | M20-7820446 | 0 | M20-7820446 |  |  | PLUG_01X04_254
 |  | P7 | PLUG_01X04_254 | os_conn_strip:PLUG_01X04_254 | Socket_Strips:Socket_Strip_Straight_1x04 |  |  | Harwin | M20-7820446 | 0 | M20-7820446 |  |  | PLUG_01X04_254
 |  | P8 | PLUG_01X04_254 | os_conn_strip:PLUG_01X04_254 | Socket_Strips:Socket_Strip_Straight_1x04 |  |  | Harwin | M20-7820446 | 0 | M20-7820446 |  |  | PLUG_01X04_254
 |  | R1 | R_0_0603_5 | os_resistor_SMD:R_0_0603_5 | Resistors_SMD:R_0603 |  |  | KOA Spear | RK73Z1JTTD | 0 | 0 |  |  | R_0_0603_5
 |  | R2 | R_0_0603_5 | os_resistor_SMD:R_0_0603_5 | Resistors_SMD:R_0603 |  |  | KOA Spear | RK73Z1JTTD | 0 | 0 |  |  | R_0_0603_5
 |  | R3 | R_0_0603_5 | os_resistor_SMD:R_0_0603_5 | Resistors_SMD:R_0603 |  |  | KOA Spear | RK73Z1JTTD | 0 | 0 |  |  | R_0_0603_5
 |  | R4 | R_0_0603_5 | os_resistor_SMD:R_0_0603_5 | Resistors_SMD:R_0603 |  |  | KOA Spear | RK73Z1JTTD | 0 | 0 |  |  | R_0_0603_5
 |  | R5 | R_0_0603_5 | os_resistor_SMD:R_0_0603_5 | Resistors_SMD:R_0603 |  |  | KOA Spear | RK73Z1JTTD | 0 | 0 |  |  | R_0_0603_5
 |  | R6 | R_0_0603_5 | os_resistor_SMD:R_0_0603_5 | Resistors_SMD:R_0603 |  |  | KOA Spear | RK73Z1JTTD | 0 | 0 |  |  | R_0_0603_5
 |  | R7 | R_10K_0603_5 | os_resistor_SMD:R_10K_0603_5 | Resistors_SMD:R_0603 |  |  | KOA Spear | RK73B1JTTD103J | 0 | 10k |  |  | R_10K_0603_5
 |  | R8 | R_10K_0603_5 | os_resistor_SMD:R_10K_0603_5 | Resistors_SMD:R_0603 |  |  | KOA Spear | RK73B1JTTD103J | 0 | 10k |  |  | R_10K_0603_5
 |  | R9 | R_10K_0603_5 | os_resistor_SMD:R_10K_0603_5 | Resistors_SMD:R_0603 |  |  | KOA Spear | RK73B1JTTD103J | 0 | 10k |  |  | R_10K_0603_5
 |  | R10 | R_1K_0603_5 | os_resistor_SMD:R_1K_0603_5 | Resistors_SMD:R_0603 |  |  | KOA Spear | RK73B1JTTD102J | 0 | 1k |  |  | R_1K_0603_5
 |  | R11 | R_10K_0603_5 | os_resistor_SMD:R_10K_0603_5 | Resistors_SMD:R_0603 |  |  | KOA Spear | RK73B1JTTD103J | 0 | 10k |  |  | R_10K_0603_5
 |  | R12 | R_1K_0603_5 | os_resistor_SMD:R_1K_0603_5 | Resistors_SMD:R_0603 |  |  | KOA Spear | RK73B1JTTD102J | 0 | 1k |  |  | R_1K_0603_5
 |  | R13 | R_10K_0603_5 | os_resistor_SMD:R_10K_0603_5 | Resistors_SMD:R_0603 |  |  | KOA Spear | RK73B1JTTD103J | 0 | 10k |  |  | R_10K_0603_5
 |  | R14 | R_100_0603_5 | os_resistor_SMD:R_100_0603_5 | Resistors_SMD:R_0603 |  |  | KOA Spear | RK73B1JTTD101J | 0 | 100 |  |  | R_100_0603_5
 |  | R15 | R_100_0603_5 | os_resistor_SMD:R_100_0603_5 | Resistors_SMD:R_0603 |  |  | KOA Spear | RK73B1JTTD101J | 0 | 100 |  |  | R_100_0603_5
 |  | R16 | R_2K4_1206_5 | os_resistor_SMD:R_2K4_1206_5 | Resistors_SMD:R_1206 |  |  | KOA Spear | RK73B2BTTD242J | 0 | 2.4K |  |  | R_2K4_1206_5
 |  | R17 | R_2K4_1206_5 | os_resistor_SMD:R_2K4_1206_5 | Resistors_SMD:R_1206 |  |  | KOA Spear | RK73B2BTTD242J | 0 | 2.4K |  |  | R_2K4_1206_5
 |  | R18 | R_2K4_1206_5 | os_resistor_SMD:R_2K4_1206_5 | Resistors_SMD:R_1206 |  |  | KOA Spear | RK73B2BTTD242J | 0 | 2.4K |  |  | R_2K4_1206_5
 |  | R19 | R_2K4_1206_5 | os_resistor_SMD:R_2K4_1206_5 | Resistors_SMD:R_1206 |  |  | KOA Spear | RK73B2BTTD242J | 0 | 2.4K |  |  | R_2K4_1206_5
 |  | U1 | TCA9554 | TI_I2C:TCA9554 | Housings_SSOP:SSOP-16_3.9x4.9mm_Pitch0.635mm |  |  | TI | TCA9554DBQR | 0 |  |  |  | TCA9554
 |  | U2 | TLP291(SE | os_optocoupler:TLP291(SE | os_optocoupler:TLP291 |  |  | Toshiba | TLP291(SE | 0 | TLP291(SE |  |  | TLP291(SE
 |  | U3 | TLP291(SE | os_optocoupler:TLP291(SE | os_optocoupler:TLP291 |  |  | Toshiba | TLP291(SE | 0 | TLP291(SE |  |  | TLP291(SE
Collated Components:
Item | Qty | Reference(s) | Value | LibPart | Footprint | Datasheet | CERAMIC | MF | MF_PN | NOPOP | VAL | VALUE | VOLTAGE | Value
1 | 1 | C1 | C_100n_0603_10_X7R_25V | os_capacitor_SMD:C_100n_0603_10_X7R_25V | Capacitors_SMD:C_0603 |  | X7R | Murata | GRM188R71E104KA01D | 0 |  | 100n | 25V | C_100n_0603_10_X7R_25V
2 | 1 | C2 | C_1u_0603_10_X7R_25V | os_capacitor_SMD:C_1u_0603_10_X7R_25V | Capacitors_SMD:C_0603 |  | X7R | Murata | GRJ188R71E105KE11D | 0 |  | 1u | 25V | C_1u_0603_10_X7R_25V
3 | 2 | D1, D2 | TVS_SMC_49.1V | tvs:TVS_SMC_49.1V | Diodes_SMD:SMC_Standard |  |  | BOURNS | SMLJ40CA | 0 |  |  |  | 49.1V
4 | 8 | P1, P2, P3, P4, P5, P6, P7, P8 | PLUG_01X04_254 | os_conn_strip:PLUG_01X04_254 | Socket_Strips:Socket_Strip_Straight_1x04 |  |  | Harwin | M20-7820446 | 0 | M20-7820446 |  |  | PLUG_01X04_254
5 | 6 | R1, R2, R3, R4, R5, R6 | R_0_0603_5 | os_resistor_SMD:R_0_0603_5 | Resistors_SMD:R_0603 |  |  | KOA Spear | RK73Z1JTTD | 0 | 0 |  |  | R_0_0603_5
6 | 5 | R7, R8, R9, R11, R13 | R_10K_0603_5 | os_resistor_SMD:R_10K_0603_5 | Resistors_SMD:R_0603 |  |  | KOA Spear | RK73B1JTTD103J | 0 | 10k |  |  | R_10K_0603_5
7 | 2 | R10, R12 | R_1K_0603_5 | os_resistor_SMD:R_1K_0603_5 | Resistors_SMD:R_0603 |  |  | KOA Spear | RK73B1JTTD102J | 0 | 1k |  |  | R_1K_0603_5
8 | 2 | R14, R15 | R_100_0603_5 | os_resistor_SMD:R_100_0603_5 | Resistors_SMD:R_0603 |  |  | KOA Spear | RK73B1JTTD101J | 0 | 100 |  |  | R_100_0603_5
9 | 4 | R16, R17, R18, R19 | R_2K4_1206_5 | os_resistor_SMD:R_2K4_1206_5 | Resistors_SMD:R_1206 |  |  | KOA Spear | RK73B2BTTD242J | 0 | 2.4K |  |  | R_2K4_1206_5
10 | 1 | U1 | TCA9554 | TI_I2C:TCA9554 | Housings_SSOP:SSOP-16_3.9x4.9mm_Pitch0.635mm |  |  | TI | TCA9554DBQR | 0 |  |  |  | TCA9554
11 | 2 | U2, U3 | TLP291(SE | os_optocoupler:TLP291(SE | os_optocoupler:TLP291 |  |  | Toshiba | TLP291(SE | 0 | TLP291(SE |  |  | TLP291(SE

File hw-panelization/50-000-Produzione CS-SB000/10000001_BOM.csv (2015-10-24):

Id | Riferimento | Contenitore | Quantità | Valore | Produttore
1 | U1 | SO16L | 1 | PCF8574
2 | R13,R11,R9,R8,R7 | SM0603 | 5 | 10000
3 | R12,R10 | SM0603 | 2 | 1000
4 | R1,R2,R3,R4,R5,R6 | SM0603 | 6 | 0
5 | P8,P7,P6,P5,P4,P3,P2,P1 | PIN_ARRAY_4x1 | 8 | CONN_4
6 | D2,D1 | DO214 | 2 | ZENERSMALL
7 | R17,R19,R18,R16 | SM2512 | 4 | 2400
8 | R15,R14 | SM0603 | 2 | 100
9 | IC1,IC2 | optocoupler-2-MINI-FLAT-4 | 2 | TLP291
10 | MH1,MH2 | MountingHole_3-5mm | 2 | MountingHole_3-5mm
11 | FID1 | Fiducial_Modern_CopperTop | 1 | Fiducial_Modern_CopperTop
12 | C1 | C_0603 | 1 | 100n
13 | C2 | C_0603 | 1 | 1u

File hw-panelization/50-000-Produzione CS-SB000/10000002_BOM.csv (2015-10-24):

Id | Riferimento | Contenitore | Quantità | Valore | Produttore
1 | U1 | SO16L | 1 | PCF8574
2 | R13,R11,R9,R8,R7 | SM0603 | 5 | 10000
3 | R12,R10 | SM0603 | 2 | 1000
4 | R1,R2,R3,R4,R5,R6 | SM0603 | 6 | 0
5 | P8,P7,P6,P5,P4,P3,P2,P1 | PIN_ARRAY_4x1 | 8 | CONN_4
6 | D2,D1 | DO214 | 2 | ZENERSMALL
7 | U3,U2 | AQZ-SIL-4 | 2 | AQZ204
8 | FID1 | Fiducial_Modern_CopperTop | 1 | Fiducial_Modern_CopperTop
9 | MH1,MH2 | MountingHole_3-5mm | 2 | MountingHole_3-5mm
10 | C1 | C_0603_HandSoldering | 1 | 100n
11 | C2 | C_0603_HandSoldering | 1 | 1u

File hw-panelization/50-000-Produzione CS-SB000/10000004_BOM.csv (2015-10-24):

Id | Riferimento | Contenitore | Quantità | Valore | Produttore
1 | U1 | SSOP-28_5.3x10.2mm_Pitch0.65mm | 1 | FT232RL
2 | P7,P6,P5,P4,P3,P2,P1 | PIN_ARRAY_4x1 | 7 | CONN_01X04
3 | FID1 | Fiducial_Modern_CopperTop | 1 | Fiducial_Modern_CopperTop
4 | MH1,MH2 | MountingHole_3-5mm | 2 | MountingHole_3-5mm
5 | C1,C3,C4 | C_0603 | 3 | 100n
6 | C2 | C_0603 | 1 | 1u
7 | C5 | TantalC_SizeA_EIA-3216_HandSoldering | 1 | 4.7u
8 | C6 | C_0603_HandSoldering | 1 | 10n
9 | D1,D2 | LED-0603 | 2 | LED
10 | FB1 | C_0805 | 1 | FILTER
11 | P9,P10,P11,P12 | Pin_Header_Straight_1x01 | 4 | CONN_01X01
12 | R1,R2 | R_0603 | 2 | 270
13 | R3,R4,R5,R6,R7,R8,R9,R10,R11,R12 | R_0603 | 10 | 0
14 | CON1 | conn_usb_B_micro_smd | 1 | USB-MICRO-B

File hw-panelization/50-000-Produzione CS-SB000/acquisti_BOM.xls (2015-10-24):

Id | Riferimento | Contenitore | QuantitÃ | Valore | Produttore | Codice produttore | Categoria | Scheda
1 | U1 | SO16L | 1 | PCF8574 | NXP | PCF8574T/3,518 | U | IN | http://www.mouser.it/ProductDetail/NXP-Semiconductors/PCF8574T-3518/?qs=sGAEpiMZZMvKM5ialpXrmr70UmLJCSgi | 10 | 0.947 | 9.47 | 1 | 0 | 2 | 0 | ok
2 | R13,R11,R9,R8,R7 | SM0603 | 5 | 10000 | Panasonic | ERJ-3EKF1002V | R | IN | http://www.mouser.it/ProductDetail/Panasonic/ERJ-3EKF1002V/ | 100 | 0.008 | 0.8 | 1 | 0 | 2 | 0 | ok
3 | R12,R10 | SM0603 | 2 | 1000 | Panasonic | ERJ-3EKF1001V | R | IN | http://www.mouser.it/ProductDetail/Panasonic/ERJ-3EKF1001V/?qs=sGAEpiMZZMtlubZbdhIBIHcx2Q2RnT7KlVgQLdRivFY%3d | 100 | 0.008 | 0.8 | 1 | 0 | 2 | 0 | ok
4 | R1,R2,R3,R4,R5,R6 | SM0603 | 6 | 0 | Panasonic | ERJ-3GEY0R00V | R | IN | http://www.mouser.it/ProductDetail/Panasonic/ERJ-3GEY0R00V/ | 100 | 0.007 | 0.7 | 2 | 0 | 3 | 0 | ok
5 | P8,P7,P6,P5,P4,P3,P2,P1 | PIN_ARRAY_4x1 | 8 | CONN_4 | FCI | 76341-304LF | J | IN | http://www.mouser.it/ProductDetail/FCI/76341-304LF/?qs=sGAEpiMZZMvffgRu4KC1R04q9MI2j2SgEoX0VzuNj44%3d | 10 | 0.528 | 5.28 | 2 | 0 | 3 | 0 | ok
6 | D2,D1 | DO214 | 2 | ZENERSMALL | AVX | SMAJ220CA | Z | IN | http://www.mouser.it/ProductDetail/AVX/SMAJ220CA/ | 1 | 0.485 | 0.485 | 1 | 0 | 2 | 0 | ok
7 | R17,R19,R18,R16 | SM2512 | 4 | 2400 | Vishay | CRCW25122K40JNEG | R | IN | http://www.mouser.it/ProductDetail/Vishay-Dale/CRCW25122K40JNEG/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 | 100 | 0.112 | 11.2 | 0 | 1 | 1 | 40 | ok | -
8 | R15,R14 | SM0603 | 2 | 100 | Panasonic | ERJ-3EKF1000V | R | IN | http://www.mouser.it/ProductDetail/Panasonic/ERJ-3EKF1000V/?qs=sGAEpiMZZMtlubZbdhIBIHcx2Q2RnT7KrCRkR6BszlM%3d | 100 | 0.008 | 0.8 | 0 | 1 | 1 | 20 | ok | -
9 | IC1,IC2 | optocoupler-2-MINI-FLAT-4 | 2 | TLP291 | Toshiba | TLP291(GR,E) | U | IN | http://www.mouser.it/ProductDetail/Toshiba/TLP291GRE/ | 10 | 0.411 | 4.11 | 0 | 1 | 1 | 20 | ko | -
12 | C1 | C_0603 | 1 | 100n | Vishay | VJ0603Y104KXXCW1BC | C | IN | http://www.mouser.it/ProductDetail/Vishay-Vitramon/VJ0603Y104KXXCW1BC/ | 50 | 0.023 | 1.15 | 2 | 0 | 3 | 0 | ok
13 | C2 | C_0603 | 1 | 1u | Taiyo Yuden | TMK107B7105KA-T | C | IN | http://www.mouser.it/ProductDetail/Taiyo-Yuden/TMK107B7105KA-T/ | 10 | 0.036 | 0.36 | 2 | 0 | 3 | 0 | ok
1 | U1 | SO16L | 1 | PCF8574 | NXP | PCF8574T/3,518 | U | OUT | http://www.mouser.it/ProductDetail/NXP-Semiconductors/PCF8574T-3518/?qs=sGAEpiMZZMvKM5ialpXrmr70UmLJCSgi | 10 | 0.947 | 9.47 | 0 | 1 | 2 | 20 | ko | -
2 | R13,R11,R9,R8,R7 | SM0603 | 5 | 10000 | Panasonic | ERJ-3EKF1002V | R | OUT | http://www.mouser.it/ProductDetail/Panasonic/ERJ-3EKF1002V/ | 100 | 0.008 | 0.8 | 0 | 1 | 2 | 100 | ko | -
3 | R12,R10 | SM0603 | 2 | 1000 | Panasonic | ERJ-3EKF1001V | R | OUT | http://www.mouser.it/ProductDetail/Panasonic/ERJ-3EKF1001V/?qs=sGAEpiMZZMtlubZbdhIBIHcx2Q2RnT7KlVgQLdRivFY%3d | 100 | 0.008 | 0.8 | 0 | 1 | 2 | 40 | ok | -
4 | R1,R2,R3,R4,R5,R6 | SM0603 | 6 | 0 | Panasonic | ERJ-3GEY0R00V | R | OUT | http://www.mouser.it/ProductDetail/Panasonic/ERJ-3GEY0R00V/ | 100 | 0.007 | 0.7 | 1 | 0 | 3 | 0 | ok
5 | P8,P7,P6,P5,P4,P3,P2,P1 | PIN_ARRAY_4x1 | 8 | CONN_4 | FCI | 76341-304LF | J | OUT | http://www.mouser.it/ProductDetail/FCI/76341-304LF/?qs=sGAEpiMZZMvffgRu4KC1R04q9MI2j2SgEoX0VzuNj44%3d | 10 | 0.528 | 5.28 | 1 | 0 | 3 | 0 | ok
6 | D2,D1 | DO214 | 2 | ZENERSMALL | AVX | SMAJ220CA | Z | OUT | http://www.mouser.it/ProductDetail/AVX/SMAJ220CA/ | 1 | 0.485 |  | 0 | 1 | 2 | 40 | ko | -
7 | U3,U2 | AQZ-SIL-4 | 2 | AQZ204 | Panasonic | AQZ204 | U | OUT | http://www.mouser.it/ProductDetail/Panasonic-Industrial-Devices/AQZ204/ | 1 | 10.8 | 10.8 | 0 | 1 | 1 | 20 | ko | X
10 | C1 | C_0603_HandSoldering | 1 | 100n | Vishay | VJ0603Y104KXXCW1BC | C | OUT | http://www.mouser.it/ProductDetail/Vishay-Vitramon/VJ0603Y104KXXCW1BC/ | 50 | 0.023 | 1.15 | 1 | 0 | 3 | 0 | ok
11 | C2 | C_0603_HandSoldering | 1 | 1u | Taiyo Yuden | TMK107B7105KA-T | C | OUT | http://www.mouser.it/ProductDetail/Taiyo-Yuden/TMK107B7105KA-T/ | 10 | 0.036 | 0.36 | 1 | 0 | 3 | 0 | ok
1 | U1 | SSOP-28_5.3x10.2mm_Pitch0.65mm | 1 | FT232RL | FTDI | FT232RL-REEL | U | SER | http://www.mouser.it/ProductDetail/FTDI/FT232RL-REEL/?qs=sGAEpiMZZMs5ceO8zL%252bTxyQLQIH6hE7q | 1 | 4.26 | 4.26 | 0 | 1 | 1 | 10 | ko | -
2 | P7,P6,P5,P4,P3,P2,P1 | PIN_ARRAY_4x1 | 7 | CONN_01X04 | FCI | 76341-304LF | J | SER | http://www.mouser.it/ProductDetail/FCI/76341-304LF/?qs=sGAEpiMZZMvffgRu4KC1R04q9MI2j2SgEoX0VzuNj44%3d | 10 | 0.528 | 5.28 | 0 | 1 | 3 | 210 | ko | X
5 | C1,C3,C4 | C_0603 | 3 | 100n | Vishay | VJ0603Y104KXXCW1BC | C | SER | http://www.mouser.it/ProductDetail/Vishay-Vitramon/VJ0603Y104KXXCW1BC/ | 50 | 0.023 | 1.15 | 0 | 1 | 3 | 90 | ko | -
6 | C2 | C_0603 | 1 | 1u | Taiyo Yuden | TMK107B7105KA-T | C | SER | http://www.mouser.it/ProductDetail/Taiyo-Yuden/TMK107B7105KA-T/ | 10 | 0.036 | 0.36 | 0 | 1 | 3 | 30 | ko | -
7 | C5 | TantalC_SizeA_EIA-3216_HandSoldering | 1 | 4.7u | AVX | TAJA475K025RNJ | C | SER | http://www.mouser.it/ProductDetail/AVX/TAJA475K025RNJ/?qs=sGAEpiMZZMuEN2agSAc2psTMe46DsJuTkp2PmPWavjw%3d | 1 | 1.01 | 1.01 | 0 | 1 | 1 | 10 | ko | -
8 | C6 | C_0603_HandSoldering | 1 | 10n | Vishay | VJ0603Y103KXACW1BC | C | SER | http://www.mouser.it/ProductDetail/Vishay-Vitramon/VJ0603Y103KXACW1BC/ | 50 | 0.045 | 2.25 | 0 | 1 | 1 | 10 | ok | -
9 | D1,D2 | LED-0603 | 2 | LED | OSRAM | LB Q39G-L2N2-35-1 | DL | SER | http://www.mouser.it/ProductDetail/OSRAM-Opto-Semiconductors/LB-Q39G-L2N2-35-1/ | 20 | 0.125 | 2.5 | 0 | 1 | 1 | 20 | ko | -
10 | FB1 | C_0805 | 1 | FILTER | TDK | MPZ1608S601ATD25 | FB | SER | http://www.mouser.it/ProductDetail/TDK/MPZ1608S601ATD25/ | 10 | 0.082 | 0.82 | 0 | 1 | 1 | 10 | ko | -
12 | R1,R2 | R_0603 | 2 | 270 | Panasonic | ERJ-3EKF2700V | R | SER | http://www.mouser.it/ProductDetail/Panasonic/ERJ-3EKF2700V/ | 100 | 0.007 | 0.7 | 0 | 1 | 1 | 20 | ok | -
13 | R3,R4,R5,R6,R7,R8,R9,R10,R11,R12 | R_0603 | 10 | 0 | Panasonic | ERJ-3GEY0R00V | R | SER | http://www.mouser.it/ProductDetail/Panasonic/ERJ-3GEY0R00V/ | 100 | 0.007 | 0.7 | 0 | 1 | 3 | 300 | ko | -
14 | CON1 | conn_usb_B_micro_smd | 1 | USB-MICRO-B | TE | 2013499-1 | J | SER | http://www.mouser.it/ProductDetail/TE-Connectivity/2013499-1/ | 1 | 1.61 | 1.61 | 0 | 1 | 1 | 10 | ko | -
 |  |  |  |  |  |  |  |  |  |  |  | 85.155
 |  |  |  |  | FCI | 77311-101-04LF | J | DBG | http://www.mouser.it/Search/ProductDetail.aspx?qs=5xI8GKdkXll%2f8E%252bQi8rpbg%3d%3d | 10 | 0.199 | 1.99 | 0 | 1 |  |  |  | X
 |  |  |  |  | TE | 282834-4 | J | DBG | http://www.mouser.it/ProductDetail/TE-Connectivity/282834-4/ | 1 | 2.03 | 2.03 | 0 | 1 |  |  |  | -
 |  |  |  |  | TE | 282834-2 | J | DBG | http://www.mouser.it/ProductDetail/TE-Connectivity/282834-2/ | 1 | 0.787 | 0.787 | 0 | 1 |  |  |  | -

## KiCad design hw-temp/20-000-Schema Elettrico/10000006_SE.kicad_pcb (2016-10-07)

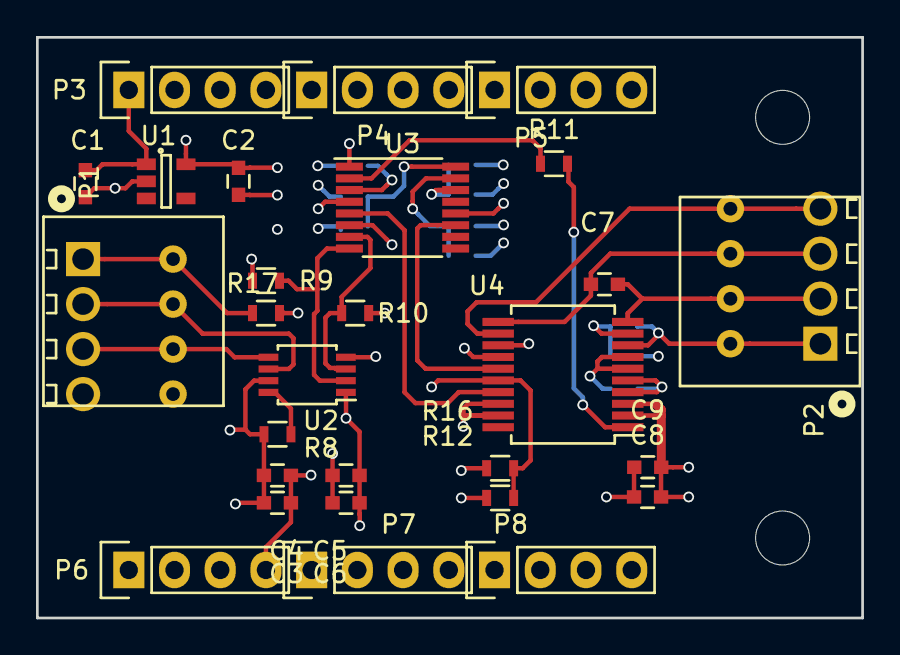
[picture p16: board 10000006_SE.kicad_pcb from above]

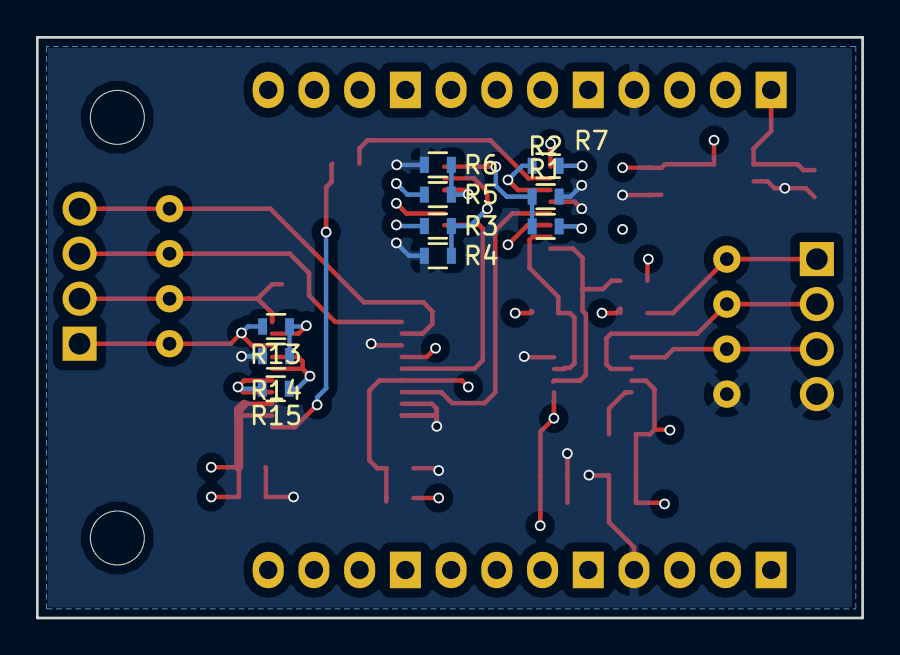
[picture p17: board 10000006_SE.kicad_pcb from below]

Board: 4 copper layers, 45.8 x 32.3 mm, 38 parts (10 on the bottom side), 25 nets.

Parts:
C1: C_1u_0603_10_X7R_25V; C_0603
C2: C_3u3_0603_10_X5R_10V; C_0603
C3, C5, C7, C8, C9: C_100n_0603_10_X7R_25V; C_0603
C4, C6: C_100p_0603_5_NP0_50V; C_0603
P1, P2: TERMINAL_01X04_250_RA_SPRING; 1770908
P3, P4, P5, P6, P7, P8: PLUG_01X04_254; Socket_Strip_Straight_1x04
R1, R2, R3, R4, R5, R6, R7, R8, R9, R10, R11, R12, R14, R15, R16: R_10K_0603_5; R_0603
R13: R_402_0603_1; R_0603
R17: R_0_0603_5; R_0603
U1: TPS709; SOT-23-5
U2: PCA9306DC; TSSOP-8_3x3mm_Pitch0.65mm
U3: SC18IS602BIPW; TSSOP-16_4.4x5mm_Pitch0.65mm
U4: MAX31865; SSOP-20_5.3x7.2mm_Pitch0.65mm

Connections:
+3V3: C2.1, C5.1, C6.1, C8.1, C9.1, R1.2, R3.2, R5.2, R7.2, R9.2, R10.2, R12.2, R17.1, U1.5, U2.1, U3.12, U4.2, U4.3
+5V: C1.1, C3.1, C4.1, P1.1, P1.5, P3.1, P6.1, R8.2, R17.2, U1.1, U2.7
/BIAS: R13.1, U4.4, U4.5
/DATA_RDYn: R11.2, U4.1
/FORCE2: R14.2, R15.2, U4.9
/FORCE_N: P2.4, P2.8, U4.12
/FORCE_P: P2.1, P2.5, R14.1, U4.8
/GPIO0: R12.1, R16.2, U3.1, U4.16
/GPIO1: R11.1, U3.2
/I2C_SCL: P1.2, P1.6, P3.2, P6.2, U2.6
/I2C_SCL_3V3: R9.1, U2.2, U3.8
/I2C_SDA: P1.3, P1.7, P3.3, P6.3, U2.5
/I2C_SDA_3V3: R10.1, U2.3, U3.7
/ISENSOR: R13.2, U4.6, U4.7
/RTDIN_N: C7.2, P2.3, P2.7, U4.11
/RTDIN_P: C7.1, P2.2, P2.6, U4.10
/SPI_CLK: U3.11, U4.15
/SPI_MISO: U3.5, U4.17
/SPI_MOSI: U3.6, U4.14
GND: C1.2, C2.2, C3.2, C4.2, C5.2, C6.2, C8.2, C9.2, P1.4, P1.8, P3.4, P6.4, R2.1, R4.1, R6.1, R15.1, R16.1, U1.2, U2.4, U3.4, U4.13, U4.18, U4.19
unnamed: R1.1, R2.2, U3.16
unnamed: R3.1, R4.2, U3.15
unnamed: R5.1, R6.2, U3.14
unnamed: R7.1, U3.3
unnamed: R8.1, U2.8

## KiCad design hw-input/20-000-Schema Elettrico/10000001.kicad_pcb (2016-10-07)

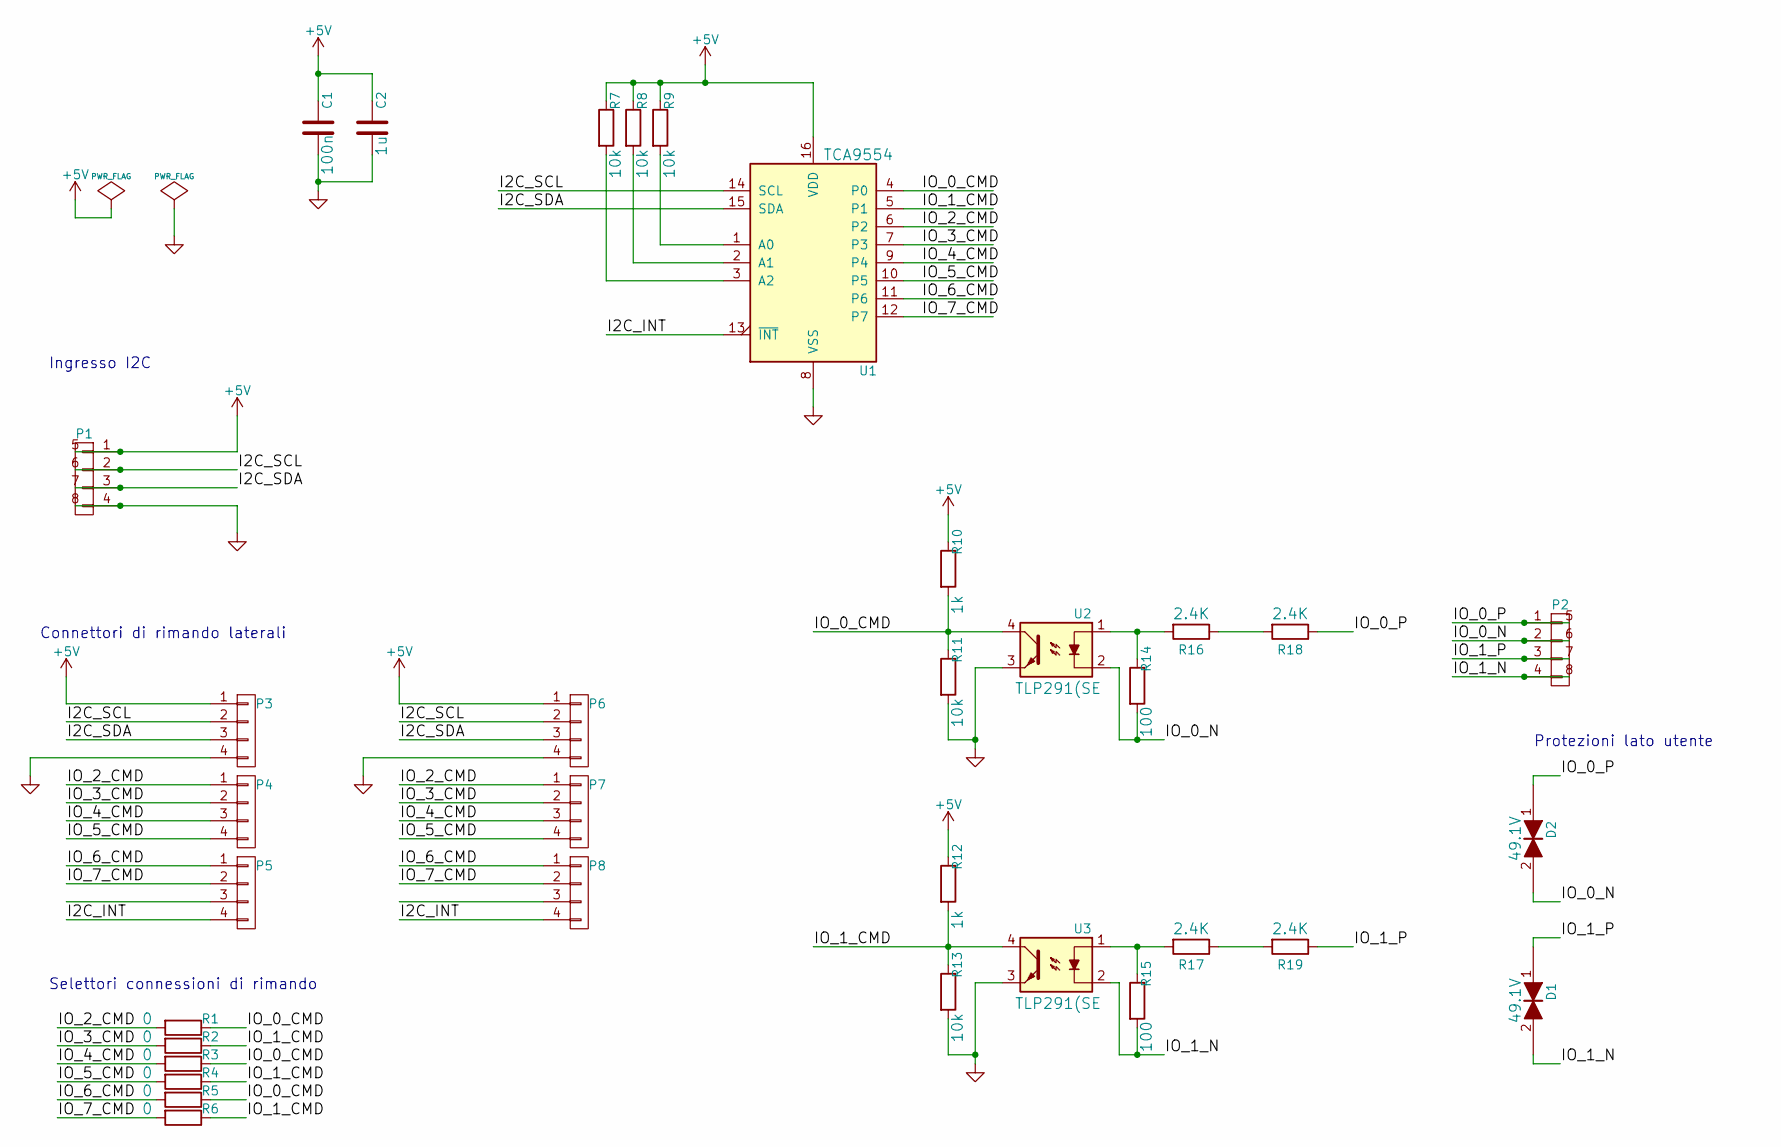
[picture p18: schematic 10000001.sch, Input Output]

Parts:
C1: C_100n_0603_10_X7R_25V; C_0603; VOLTAGE 25V
C2: C_1u_0603_10_X7R_25V; C_0603; VOLTAGE 25V
D1, D2: TVS_SMC_49.1V; SMC_Standard
P1, P2: TERMINAL_01X04_250_RA_SPRING; 1770908
P3, P4, P5, P6, P7, P8: PLUG_01X04_254; Socket_Strip_Straight_1x04
R1, R2, R3, R4, R5, R6: R_0_0603_5; R_0603
R7, R8, R9, R11, R13: R_10K_0603_5; R_0603
R10, R12: R_1K_0603_5; R_0603
R14, R15: R_100_0603_5; R_0603
R16, R17, R18, R19: R_2K4_1206_5; R_1206
U1: TCA9554; SSOP-16_3.9x4.9mm_Pitch0.635mm
U2, U3: TLP291(SE; TLP291

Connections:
+5V: C1.1, C2.1, P1.1, P1.5, P3.1, P6.1, R7.1, R8.1, R9.1, R10.1, R12.1, U1.16 (VDD)
/I2C_INT: P5.4, P8.4, U1.13 (~INT~)
/I2C_SCL: P1.2, P1.6, P3.2, P6.2, U1.14 (SCL)
/I2C_SDA: P1.3, P1.7, P3.3, P6.3, U1.15 (SDA)
/IO_0_CMD: R1.1, R3.1, R5.1, R10.2, R11.1, U1.4 (P0), U2.4
/IO_0_N: D1.2, P2.2, P2.6, R14.2, U2.2
/IO_0_P: D1.1, P2.1, P2.5, R18.1
/IO_1_CMD: R2.1, R4.1, R6.1, R12.2, R13.1, U1.5 (P1), U3.4
/IO_1_N: D2.2, P2.4, P2.8, R15.2, U3.2
/IO_1_P: D2.1, P2.3, P2.7, R19.1
/IO_2_CMD: P4.1, P7.1, R1.2, U1.6 (P2)
/IO_3_CMD: P4.2, P7.2, R2.2, U1.7 (P3)
/IO_4_CMD: P4.3, P7.3, R3.2, U1.9 (P4)
/IO_5_CMD: P4.4, P7.4, R4.2, U1.10 (P5)
/IO_6_CMD: P5.1, P8.1, R5.2, U1.11 (P6)
/IO_7_CMD: P5.2, P8.2, R6.2, U1.12 (P7)
GND: C1.2, C2.2, P1.4, P1.8, P3.4, P6.4, R11.2, R13.2, U1.8 (VSS), U2.3, U3.3
unnamed: R7.2, U1.3 (A2)
unnamed: R8.2, U1.2 (A1)
unnamed: R9.2, U1.1 (A0)
unnamed: R14.1, R16.2, U2.1
unnamed: R15.1, R17.2, U3.1
unnamed: R16.1, R18.2
unnamed: R17.1, R19.2

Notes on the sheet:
Ingresso I2C
Connettori di rimando laterali
Selettori connessioni di rimando
Protezioni lato utente

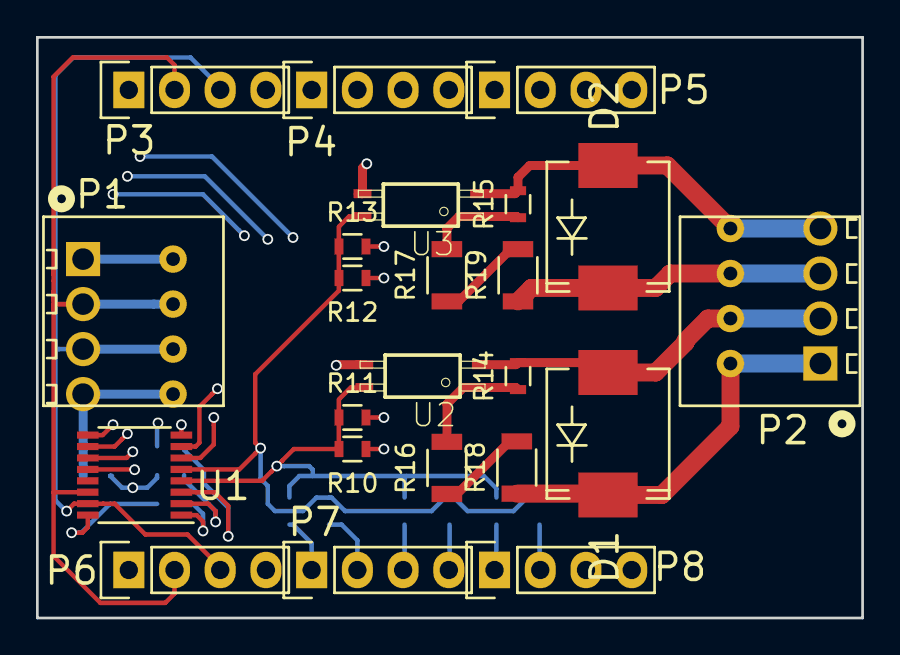
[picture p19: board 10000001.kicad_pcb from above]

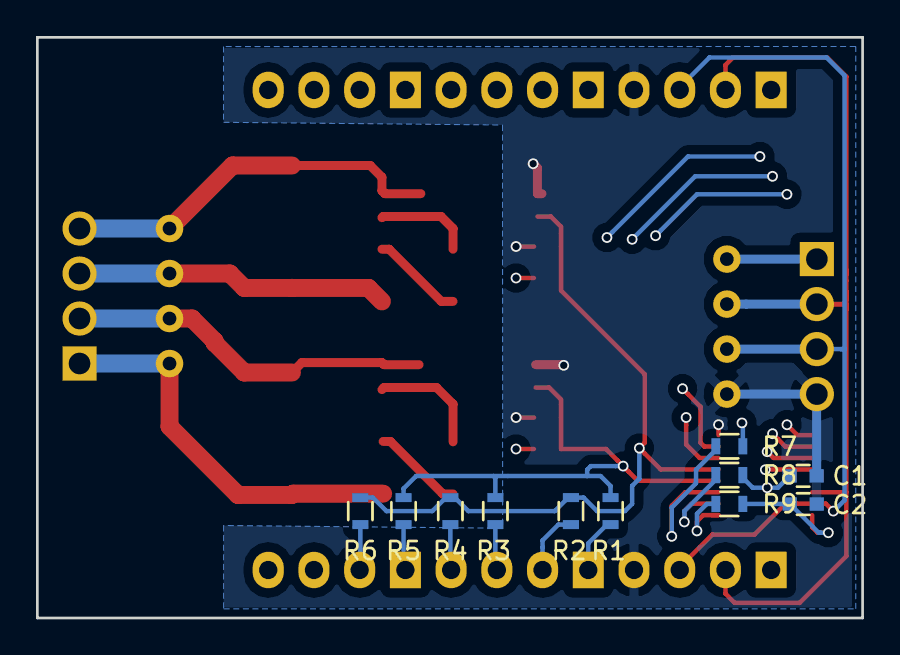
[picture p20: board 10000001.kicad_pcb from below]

Board: 4 copper layers, 45.8 x 32.3 mm, 34 parts (11 on the bottom side), 24 nets.

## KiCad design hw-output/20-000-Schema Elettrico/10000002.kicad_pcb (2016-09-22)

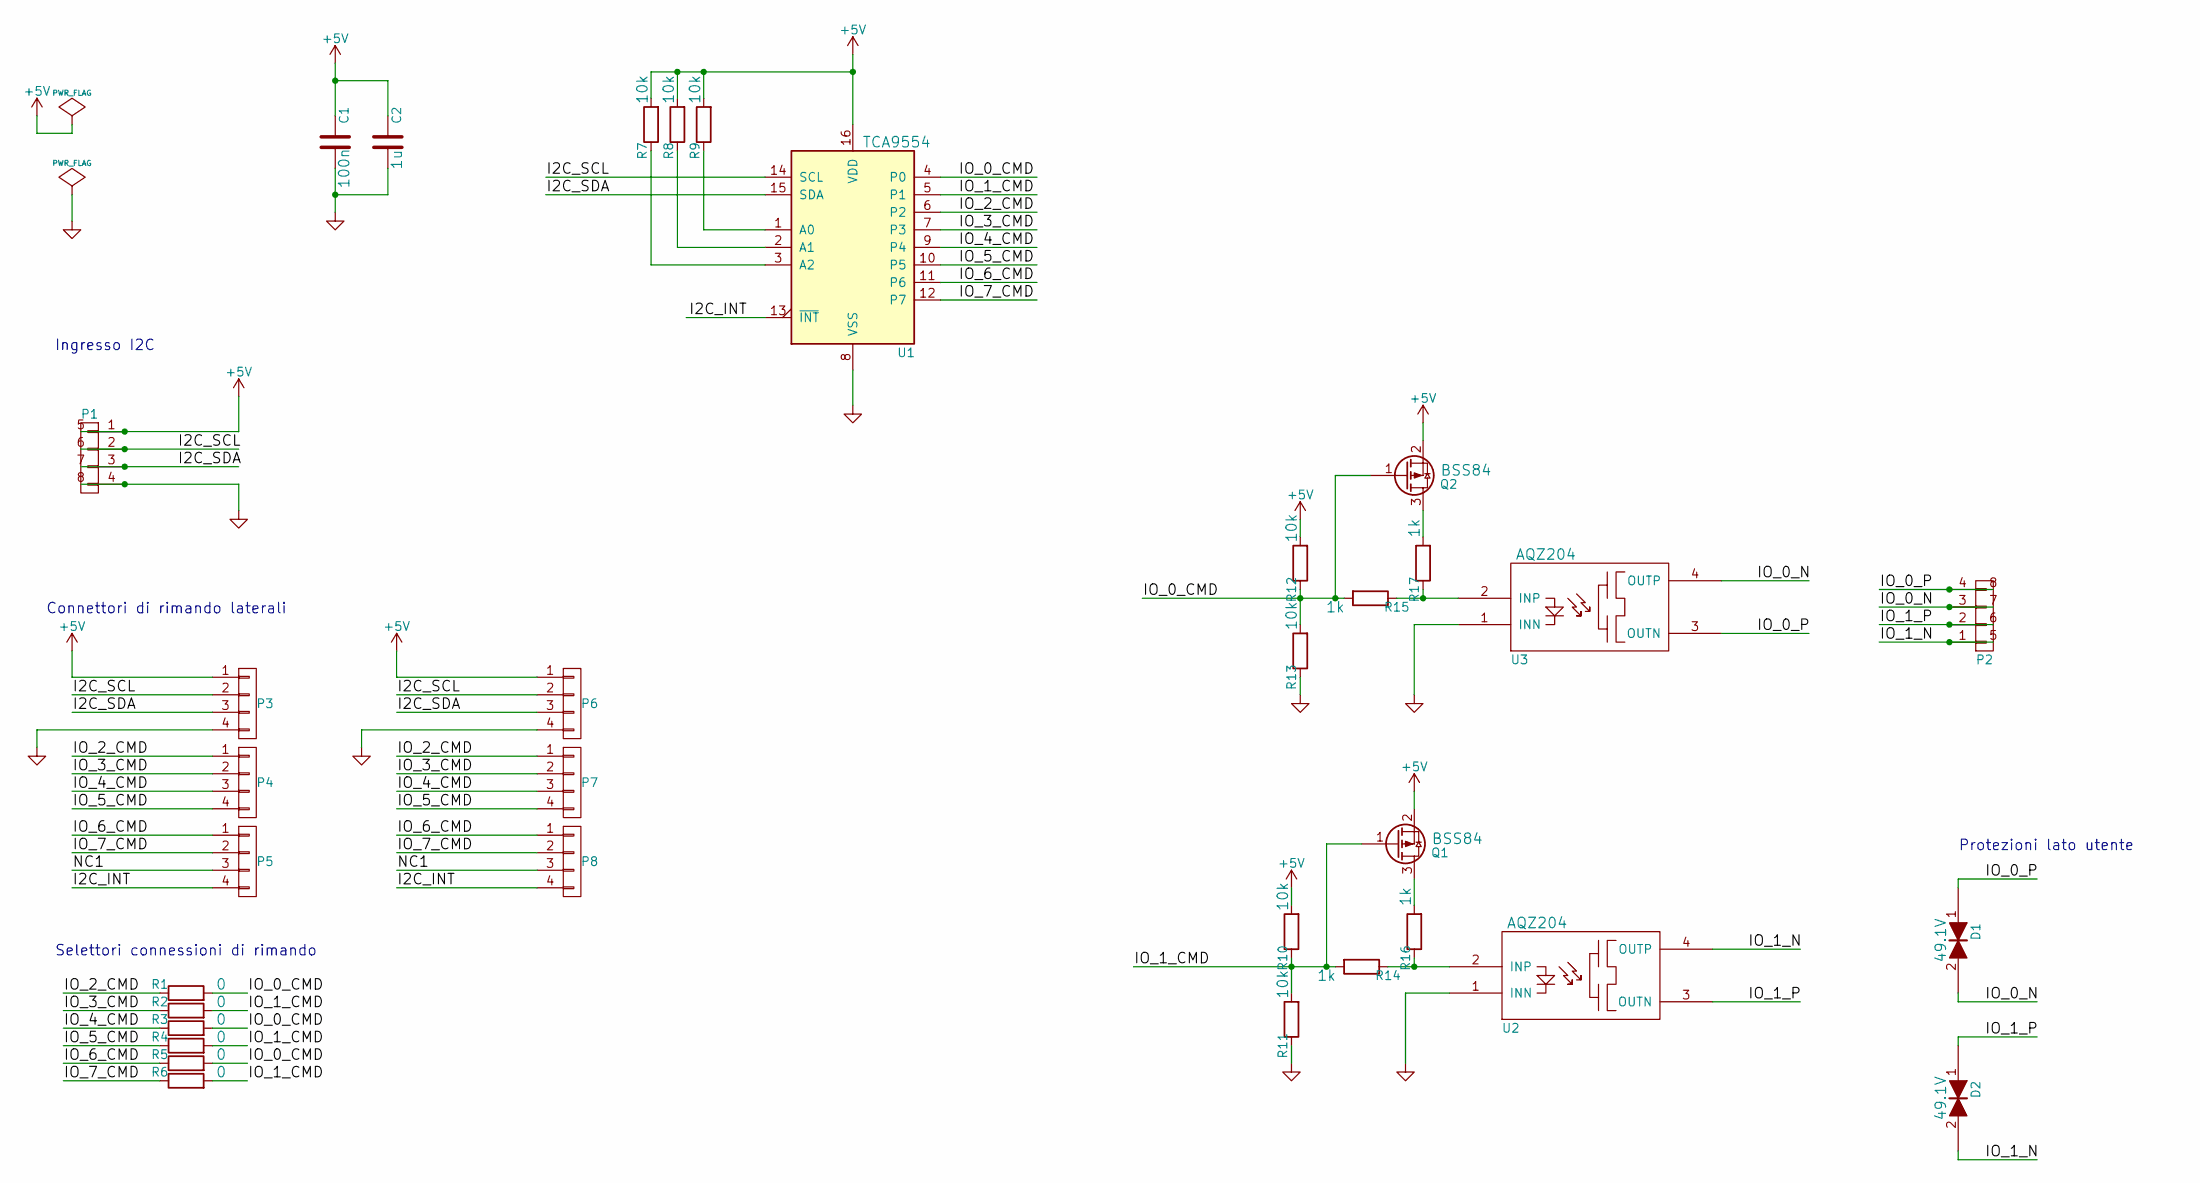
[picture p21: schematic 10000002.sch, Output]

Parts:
C1: C_100n_0603_10_X7R_25V; C_0603; VOLTAGE 25V
C2: C_1u_0603_10_X7R_25V; C_0603; VOLTAGE 25V
D1, D2: TVS_SMC_49.1V; SMC_Standard
P1, P2: TERMINAL_01X04_250_RA_SPRING; 1770908
P3, P4, P5, P6, P7, P8: PLUG_01X04_254; Socket_Strip_Straight_1x04
Q1, Q2: Q_PMOS_GSD_BSS84; SOT-23
R1, R2, R3, R4, R5, R6: R_0_0603_5; R_0603
R7, R8, R9, R10, R11, R12, R13: R_10K_0603_5; R_0603
R14, R15, R16, R17: R_1K_0603_5; R_0603
U1: TCA9554; SSOP-16_3.9x4.9mm_Pitch0.635mm
U2, U3: AQZ204; AQZ-SIL-4

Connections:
+5V: C1.1, C2.1, P1.1, P1.5, P3.1, P6.1, Q1.2 (S), Q2.2 (S), R7.2, R8.2, R9.2, R10.2, R12.2, U1.16 (VDD)
/I2C_INT: P5.4, P8.4, U1.13 (~INT~)
/I2C_SCL: P1.2, P1.6, P3.2, P6.2, U1.14 (SCL)
/I2C_SDA: P1.3, P1.7, P3.3, P6.3, U1.15 (SDA)
/IO_0_CMD: Q2.1 (G), R1.2, R3.2, R5.2, R12.1, R13.2, R15.2, U1.4 (P0)
/IO_0_N: D1.2, P2.3, P2.7, U3.4 (OUTP)
/IO_0_P: D1.1, P2.4, P2.8, U3.3 (OUTN)
/IO_1_CMD: Q1.1 (G), R2.2, R4.2, R6.2, R10.1, R11.2, R14.2, U1.5 (P1)
/IO_1_N: D2.2, P2.1, P2.5, U2.4 (OUTP)
/IO_1_P: D2.1, P2.2, P2.6, U2.3 (OUTN)
/IO_2_CMD: P4.1, P7.1, R1.1, U1.6 (P2)
/IO_3_CMD: P4.2, P7.2, R2.1, U1.7 (P3)
/IO_4_CMD: P4.3, P7.3, R3.1, U1.9 (P4)
/IO_5_CMD: P4.4, P7.4, R4.1, U1.10 (P5)
/IO_6_CMD: P5.1, P8.1, R5.1, U1.11 (P6)
/IO_7_CMD: P5.2, P8.2, R6.1, U1.12 (P7)
/NC1: P5.3, P8.3
GND: C1.2, C2.2, P1.4, P1.8, P3.4, P6.4, R11.1, R13.1, U1.8 (VSS), U2.1 (INN), U3.1 (INN)
unnamed: Q1.3 (D), R16.2
unnamed: Q2.3 (D), R17.2
unnamed: R7.1, U1.3 (A2)
unnamed: R8.1, U1.2 (A1)
unnamed: R9.1, U1.1 (A0)
unnamed: R14.1, R16.1, U2.2 (INP)
unnamed: R15.1, R17.1, U3.2 (INP)

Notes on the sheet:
Ingresso I2C
Connettori di rimando laterali
Selettori connessioni di rimando
Protezioni lato utente

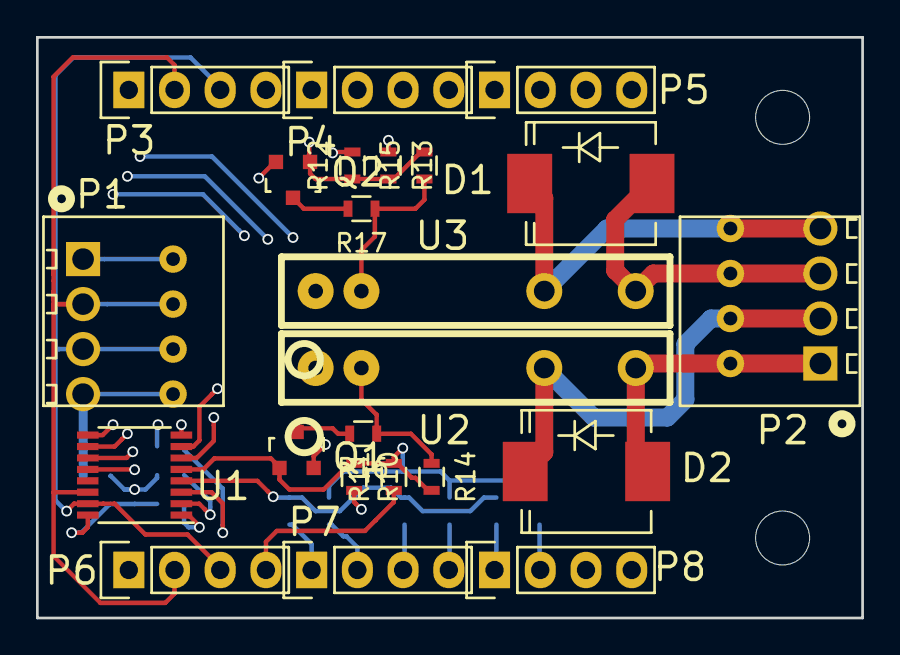
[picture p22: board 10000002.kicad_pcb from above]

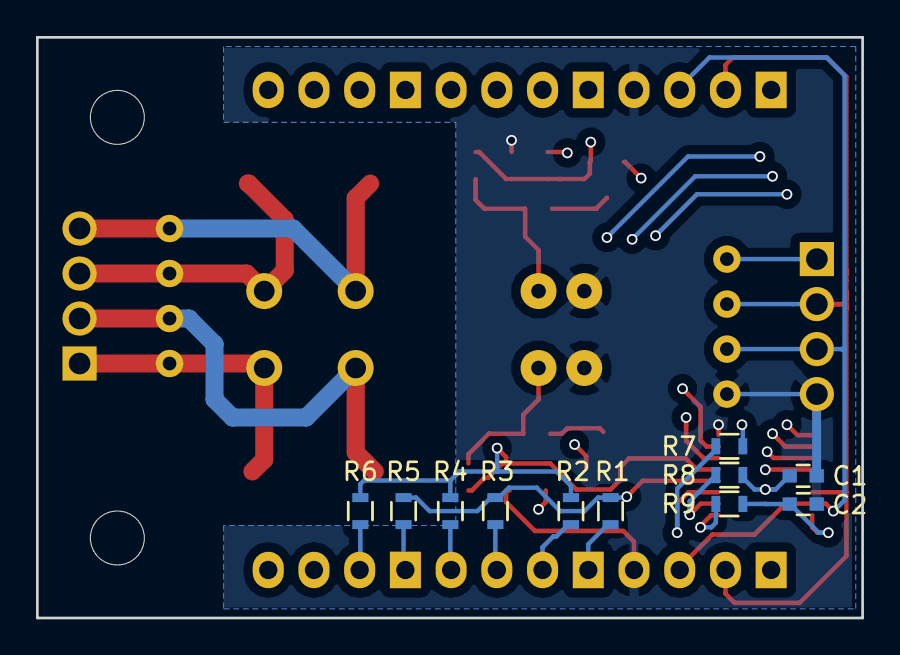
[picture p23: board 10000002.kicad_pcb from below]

Board: 4 copper layers, 45.8 x 32.3 mm, 34 parts (11 on the bottom side), 25 nets.

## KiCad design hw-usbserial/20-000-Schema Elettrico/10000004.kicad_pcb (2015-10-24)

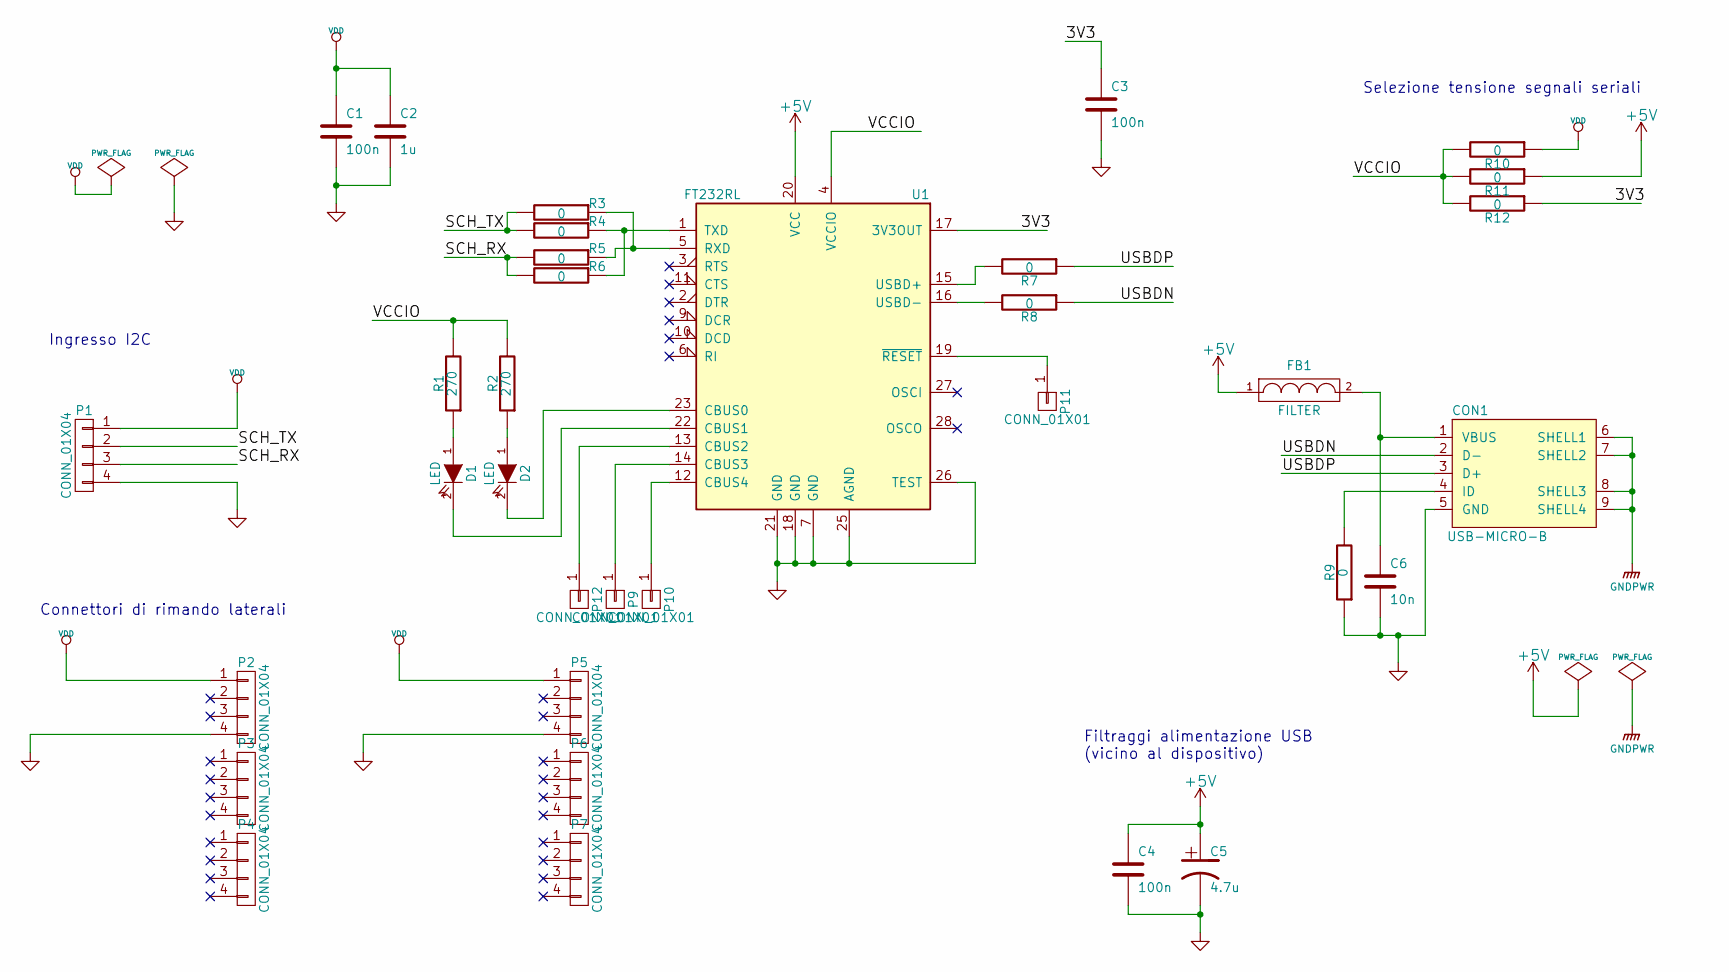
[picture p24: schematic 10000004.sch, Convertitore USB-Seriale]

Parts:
C1, C3, C4: 100n; C_0603
C2: 1u; C_0603
C5: 4.7u
C6: 10n; C_0603_HandSoldering
CON1: USB-MICRO-B; conn_usb_B_micro_smd
D1, D2: LED; LED-0603
FB1: FILTER; C_0805
P1, P2, P3, P4, P5, P6, P7: CONN_01X04; Pin_Header_Straight_1x04
P9, P10, P11, P12: CONN_01X01; Pin_Header_Straight_1x01
R1, R2: 270; R_0603
R3, R4, R5, R6, R7, R8, R9, R10, R11, R12: 0; R_0603
U1: FT232RL; SSOP-28_5.3x10.2mm_Pitch0.65mm

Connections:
+5V: C4.1, C5.1, FB1.1, R11.1, U1.20 (VCC)
/3V3: C3.1, R12.1, U1.17 (3V3OUT)
/SCH_RX: P1.3, R5.2, R6.2
/SCH_TX: P1.2, R3.2, R4.2
/USBDN: CON1.2 (D-), R8.1
/USBDP: CON1.3 (D+), R7.1
/VCCIO: R1.2, R2.2, R10.2, R11.2, R12.2, U1.4 (VCCIO)
GND: C1.2, C2.2, C3.2, C4.2, C5.2, C6.2, CON1.5 (GND), P1.4, P2.4, P5.4, R9.1, U1.7 (GND), U1.18 (GND), U1.21 (GND), U1.25 (AGND), U1.26 (TEST)
unnamed: C6.1, CON1.1 (VBUS), FB1.2
unnamed: CON1.4 (ID), R9.2
unnamed: D1.1 (A), R1.1
unnamed: D1.2 (K), U1.22 (CBUS1)
unnamed: D2.1 (A), R2.1
unnamed: D2.2 (K), U1.23 (CBUS0)
unnamed: P9.1, U1.14 (CBUS3)
unnamed: P10.1, U1.12 (CBUS4)
unnamed: P11.1, U1.19 (~RESET~)
unnamed: P12.1, U1.13 (CBUS2)
unnamed: R3.1, R5.1, U1.5 (RXD)
unnamed: R4.1, R6.1, U1.1 (TXD)
unnamed: R7.2, U1.15 (USBD+)
unnamed: R8.2, U1.16 (USBD-)
VDD: C1.1, C2.1, P1.1, P2.1, P5.1, R10.1

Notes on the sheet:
Ingresso I2C
Connettori di rimando laterali
Selezione tensione segnali seriali
Filtraggi alimentazione USB (vicino al dispositivo)

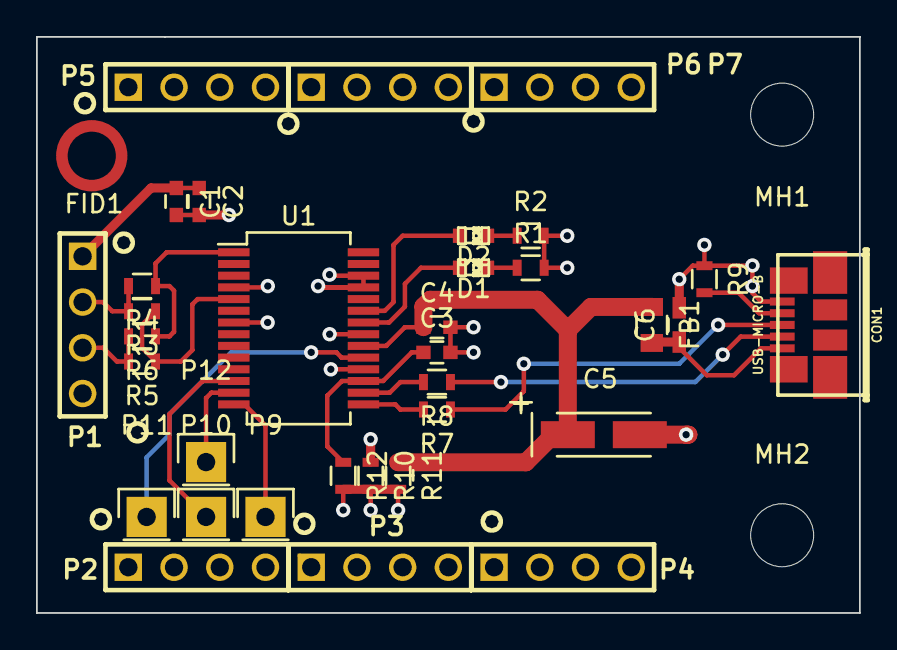
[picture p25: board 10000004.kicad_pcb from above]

Board: 4 copper layers, 45.7 x 32.0 mm, 37 parts (0 on the bottom side), 23 nets.

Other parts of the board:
FID1: Fiducial_Modern_CopperTop
MH1, MH2: MountingHole_3-5mm

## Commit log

2014-10-23 Commit struttura cartelle e schema vuoto. Commit documenti di descrizione schemi base.
    [10000001.kicad_pcb, 10000001.sch]
2014-11-01 Aggiunto documento di specifica fisica... (forse sto esagerando)
2014-11-01 Aggiunte dimenticanze al documento di specifica fisica
2014-11-02 Aggiunti requisiti
    - Connessione 220V a.c.
    - Ingresso ADC
    - Porta RS232
2014-11-22 Aggiunti documenti di descrizione interfacce RS232, USB e distribuzione alimentazione... manca solo ADC!
    [10000001.sch]
2014-11-30 Aggiornato schematico modulo ingressi
    [10000001.sch]
2015-01-07 Aggiornato schema
    [10000001.sch]
2015-01-26 Aggiornato albero delle directory. Iniziato layout scheda uscite di potenza.
    [10000001.kicad_pcb, 10000001.sch, 10000002.brd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]
2015-01-31 Terminato sbroglio proliminare scheda uscite. Da impostare regole elettriche di isolamento e portata di corrente per terminare definitivamente. Mancano fiducial e scritte.
    [10000002.brd]
2015-02-25 Completamento sbroglio hw-output
    [10000001.brd, 10000001.kicad_pcb, 10000001.sch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]
2015-02-25 rimosse cartelle in origine
    [10000001.kicad_pcb, 10000001.sch]
2015-04-17 Scheda input ed output completate con fori di montaggio, fiducial e serigrafie.
    [10000001.kicad_pcb, 10000002.kicad_pcb]
2015-04-20 Aggiunte capacità di bypass su alimentazione I2C expander
    [10000001.kicad_pcb, 10000001.sch, 10000002.kicad_pcb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]
2015-05-22 Terminato sbroglio convertitore USB seriale.
    [10000002.kicad_pcb, 10000004.kicad_pcb, 10000004.sch]
2015-06-06 Aggiunte librerie - simosio: libreria da linkare direttamente in kicad, ma aggiunta come sottomodulo. - varie: librerie vecchio stile stand-alone da aggiungere direttamente in kicad e da eliminare in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
    Nota, provare a creare un repository di librerie nuovo stile, in cui integrare varie
2015-06-24 Generati file gerber per produzione
    [10000001-B_Cu.gbl, 10000001-B_Mask.gbs, 10000001-B_Paste.gbp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]
2015-07-17 Aggiunto file di pannellizzazione
    [10000001-B_Cu.gbl, 10000001-B_Mask.gbs, 10000001-B_Paste.gbp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]
2015-07-20 Aggiunta BOM
    [10000001_BOM.csv, 10000002_BOM.csv, 10000004_BOM.csv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]
2015-07-22 terminata BOM di acquisti
    [acquisti_BOM.xlsx]
2015-07-23 aggiornati acquisti
    [acquisti_BOM.xls]
2015-10-13 Aggiunti documenti beagle-board
2015-10-13 Aggiornato documento beagle-board con procedura di creazione SD
2015-10-17 Aggiunta prima documentazione scheda misura temperatura
2015-10-20 Aggiunti documenti sensore di temperatura
2015-10-20 aggiunta file di validazione beagle board
2015-10-20 Aggiunti documenti per bridge I2C to SPI
2015-11-04 Iniziato schema misura temperatura con PT100
2015-11-18 Commit partizle avanzamento schematico scheda analogica.
2015-11-18 Aggiunti datasheet LDO e level translator per scheda temperatura
2015-12-10 Terminato schema scheda misura temperatura
2016-01-08 Aggiornato schema scheda temperatura a nuova versione kicad. Aggiunti script e librerie per generazione diretta BOM con codici d'ordine.
    [10000001.sch, 10000006_SE.CSV, 10000006_SE.kicad_pcb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]
2016-01-20 aggiornamento completo libreria e schematico per generazione BOM
    [10000006_SE.CSV, 10000006_SE.sch]
2016-01-20 Piazzamento scheda iniziato
    [10000006_SE.kicad_pcb, 10000006_SE.sch]
2016-01-26 Pulizia schema
    [10000006_SE.kicad_pcb]
2016-01-26 Inizio nuovo schema versione 02
    [10000002.sch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]
2016-01-31 Terminato schema uscite
    [10000002.sch]
2016-09-02 Completato schema elettrico con codice produttore
    [10000001.kicad_pcb, 10000001.sch, 10000001_BOM.csv]
2016-09-02 Completato schema elettrico con codici produttore
    [10000001.sch]
2016-09-22 Completato schema e sbroglio
    [10000002.kicad_pcb, 10000002.sch, 10000002_BOM.csv]
2016-09-22 completato schema elettrico e sbroglio
    [10000001.kicad_pcb, 10000001.sch]
2016-10-07 Commit definitivo
    [10000001.kicad_pcb]
2016-10-07 PCB terminato
    [10000006_SE.kicad_pcb, 10000006_SE.sch]
